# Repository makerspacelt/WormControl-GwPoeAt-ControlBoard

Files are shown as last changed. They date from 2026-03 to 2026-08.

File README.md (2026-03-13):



---
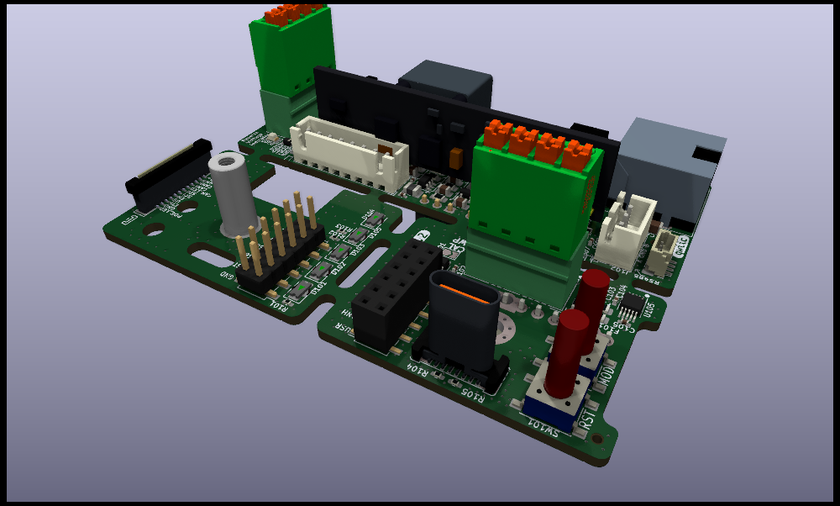
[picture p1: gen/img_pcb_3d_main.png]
PCB 3d main


WormControl Gateway POE.AT

NOTE: This is only a prototype now, so things might not work and everything might change 

Basic target features:

* Compatibility with esphome and Home Assistant

Dev NOTE: before commit, run `./kibot.sh` to regenerate documentation, bom, gerbers and other assets.

* [schematics.pdf](gen/schematics.pdf)
* [pcb.pdf with dimensions](gen/pcb.pdf)
* [ibom.html](gen/single/ibom.html)

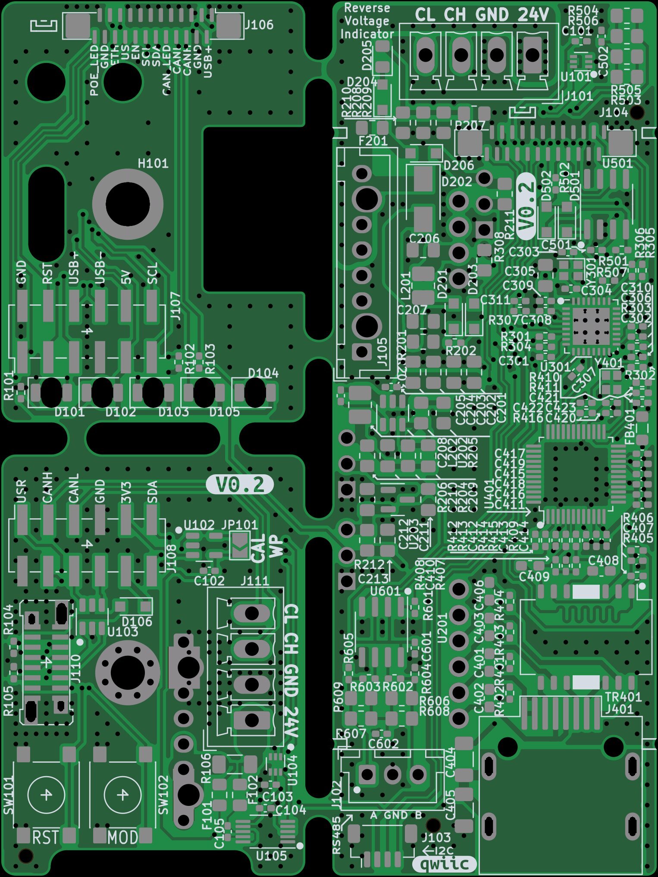
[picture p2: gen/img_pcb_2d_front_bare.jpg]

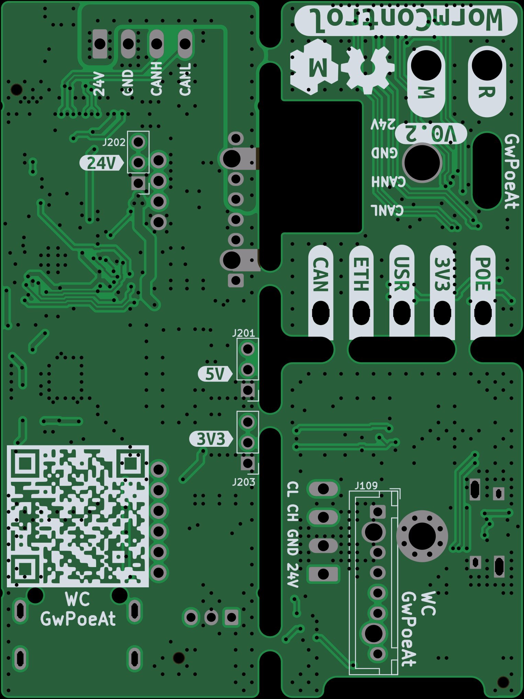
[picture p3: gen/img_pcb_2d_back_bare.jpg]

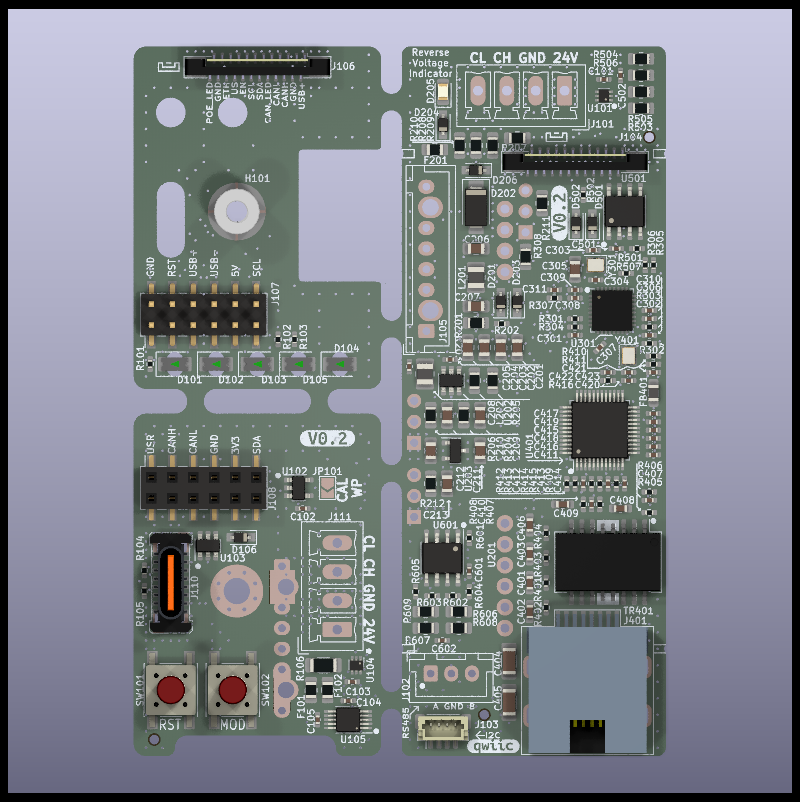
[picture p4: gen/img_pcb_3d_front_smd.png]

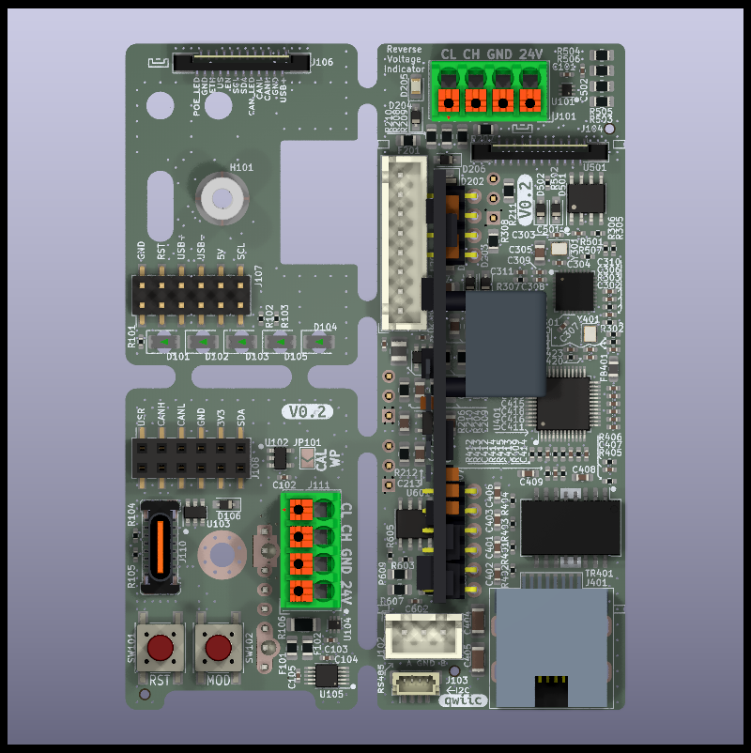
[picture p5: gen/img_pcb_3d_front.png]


---

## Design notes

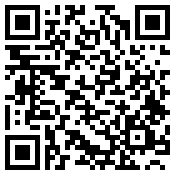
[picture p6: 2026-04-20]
gen/qr_link.png

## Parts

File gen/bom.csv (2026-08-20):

Row | Description | Part | References | Value | Footprint | Quantity Per PCB | Status | Datasheet | lcsc# | jlc-part-type | alt#
1 | Heatsink | Heatsink | BOM101,BOM102 | 1x4 screw plug | ~ | 2 |  | https://www.lcsc.com/datasheet/C7603442.pdf | C7603442 | E+
2 | Unpolarized capacitor | C | C303,C304,C422,C423 | 10p | C_0402_1005Metric_Pad0.74x0.62mm_HandSolder | 4 |  | ~ | C32949 | B+
3 | Unpolarized capacitor | C | C209 | 100p | C_0805_2012Metric_Pad1.18x1.45mm_HandSolder | 1 |  | ~ | C1790 | B+
4 | Unpolarized capacitor | C | C408,C409 | 6n8 | C_0603_1608Metric_Pad1.08x0.95mm_HandSolder | 2 |  | ~ | C1631 | B+
5 | Unpolarized capacitor | C | C101,C102,C103,C104,C105,C301,C302,C306,C307,C308,C309,C310,C311,C407,C410,C412,C413,C414,C416,C417,C418,C419,C420,C501,C502,C601,C602 | 100n | C_0402_1005Metric_Pad0.74x0.62mm_HandSolder | 27 |  | ~ | C1525 | B+
6 | Unpolarized capacitor | C | C415 | 4u7 | C_0402_1005Metric_Pad0.74x0.62mm_HandSolder | 1 |  | ~ | C23733 | B+
7 | Unpolarized capacitor | C | C205,C208 | 100n/50V | C_0402_1005Metric_Pad0.74x0.62mm_HandSolder | 2 |  | ~ | C307331 | B+
8 | Unpolarized capacitor | C | C201,C202,C203,C204,C206,C207,C210 | 10u/50v | C_0805_2012Metric_Pad1.18x1.45mm_HandSolder | 7 |  | ~ | C440198 | B+
9 | Unpolarized capacitor | C | C411,C421 | 10u/6v3 | C_0402_1005Metric_Pad0.74x0.62mm_HandSolder | 2 |  | ~ | C15525 | B+
10 | Unpolarized capacitor | C | C404 | 1n/2kv | C_1206_3216Metric_Pad1.33x1.80mm_HandSolder | 1 |  | ~ | C9196 | B+
11 | Unpolarized capacitor | C | C401,C402,C403,C406 | 22n/100v | C_0603_1608Metric_Pad1.08x0.95mm_HandSolder | 4 |  | ~ | C22374871 | E+
12 | Unpolarized capacitor | C | C211,C305 | 22u/25v | C_0805_2012Metric_Pad1.18x1.45mm_HandSolder | 2 |  | ~ | C45783 | B+
13 | Unpolarized capacitor | C | C212,C213 | 47u/6V3 | C_0805_2012Metric_Pad1.18x1.45mm_HandSolder | 2 |  | ~ | C16780 | B+
14 | Unpolarized capacitor | C | C405 | 4n7/2kv | C_1206_3216Metric_Pad1.33x1.80mm_HandSolder | 1 |  | ~ | C41017 | E+
15 | Zener diode | D_Zener | D203 | 6V8 | D_SOD-323_HandSoldering | 1 |  | https://www.lcsc.com/datasheet/C123062.pdf | C123062 | E+
16 | Schottky diode | D_Schottky | D106,D201,D204,D206,D501,D502 | B5819WS | D_SOD-323_HandSoldering | 6 |  | https://www.lcsc.com/datasheet/C8598.pdf | C8598 | B+
17 | Light emitting diode | LED | D205 | BLUE | LED_0805_2012Metric_Pad1.15x1.40mm_HandSolder | 1 |  | https://www.lcsc.com/datasheet/C2297.pdf | C2297 | B+
18 | Light emitting diode | LED | D101,D102,D103,D104,D105 | RED | LED_1206_3216Metric_ReverseMount | 5 |  | https://www.lcsc.com/datasheet/C5356080.pdf | C5356080 | E+
19 | Schottky diode | D_Schottky | D202 | SS34 | D_SMA | 1 |  | https://www.lcsc.com/datasheet/C8678.pdf | C8678 | B+
20 | Resettable fuse, polymeric positive temperature coefficient | Polyfuse | F101,F102 | 10mA | Fuse_0805_2012Metric_Pad1.15x1.40mm_HandSolder | 2 |  | https://www.lcsc.com/datasheet/C7472543.pdf | C7472543 | E+
21 | Resettable fuse, polymeric positive temperature coefficient | Polyfuse | F201 | 250mA | Fuse_0805_2012Metric_Pad1.15x1.40mm_HandSolder | 1 |  | https://www.lcsc.com/datasheet/C22378353.pdf | C22378353 | E+
22 | Ferrite bead, small symbol | FerriteBead_Small | FB401 | 600R@100MHz | L_0805_2012Metric_Pad1.05x1.20mm_HandSolder | 1 |  | ~ | C1017 | B+
23 | Generic connector, single row, 01x03, script generated (kicad-library-utils/schlib/autogen/connector/) | Conn_01x03 | J201,J202,J203 | 5V | PinHeader_1x03_P2.54mm_Vertical | 3 |  | ~ |  | -
24 | Generic screw terminal, single row, 01x04, script generated (kicad-library-utils/schlib/autogen/connector/) | Screw_Terminal_01x04 | J101,J111 | BUS | PhoenixContact_MCV_1,5_4-G-3.5_1x04_P3.50mm_Vertical | 2 |  | https://www.lcsc.com/datasheet/C880556.pdf | C880556 | E+
25 | Generic connector, single row, 01x08, script generated (kicad-library-utils/schlib/autogen/connector/) | Conn_01x08 | J105,J109 | Bot | JST_XH_B8B-XH-A_1x08_P2.50mm_Vertical | 2 |  | ~ |  | ???
26 | Generic connectable mounting pin connector, single row, 01x24, script generated (kicad-library-utils/schlib/autogen/connector/) | Conn_01x24_MountingPin | J104,J106 | FFC | AFC11-S24ICC-00 | 2 |  | https://www.lcsc.com/datasheet/C11075.pdf | C11075 | E+
27 | Generic connector, single row, 01x12, script generated (kicad-library-utils/schlib/autogen/connector/) | Conn_01x12 | J108 | Mid | PinSocket_2x06_P2.54mm_Vertical_SMD | 1 |  | https://www.lcsc.com/datasheet/C3975151.pdf | C3975151 | E+
28 | RJ connector, 8P8C (8 positions 8 connected), Shielded | RJ45_Shielded | J401 | RJ45_Shielded | RJ45_FG_RJ-064-1 | 1 |  | https://www.lcsc.com/datasheet/C7205199.pdf | C7205199 | E+
29 | Generic connector, single row, 01x12, script generated (kicad-library-utils/schlib/autogen/connector/) | Conn_01x12 | J107 | Top | PinHeader_2x06_P2.54mm_Vertical_SMD | 1 |  | https://www.lcsc.com/datasheet/C5160780.pdf | C5160780 | E+
30 | USB 2.0-only Type-C Receptacle connector | USB_C_Receptacle_USB2.0 | J110 | USB_C_Receptacle_USB2.0 | USB_C_Receptacle_G-Switch_GT-USB-7082G | 1 |  | https://www.lcsc.com/datasheet/C22383836.pdf | C22383836 | E+
31 | Generic connectable mounting pin connector, single row, 01x04, script generated (kicad-library-utils/schlib/autogen/connector/) | Conn_01x04_MountingPin | J103 | qwiic | JST_SH_BM04B-SRSS-TB_1x04-1MP_P1.00mm_Vertical | 1 |  | https://www.lcsc.com/datasheet/C51940129.pdf | C51940129 | E+
32 | Generic connector, single row, 01x03, script generated (kicad-library-utils/schlib/autogen/connector/) | Conn_01x03 | J102 | rs485 | JST_XH_B3B-XH-A_1x03_P2.50mm_Vertical | 1 |  | ~ |  | ???
33 | Inductor | L | L201,L202 | 3.3uH | L_1008_2520Metric_Pad1.43x2.20mm_HandSolder | 2 |  | https://www.lcsc.com/datasheet/C5832373.pdf | C5832373 | E+
34 | Resistor | R | R106 | 10m | R_1206_3216Metric_Pad1.30x1.75mm_HandSolder | 1 |  | ~ | C7467248 | E+
35 | Resistor | R | R206,R211,R212 | 0R1 | R_0805_2012Metric_Pad1.20x1.40mm_HandSolder | 3 |  |  | C127687 | E+
36 | Resistor | R | R602,R603 | 10R | R_0402_1005Metric_Pad0.72x0.64mm_HandSolder | 2 |  | ~ | C25077 | B+
37 | Resistor | R | R305,R306 | 22R | R_0402_1005Metric_Pad0.72x0.64mm_HandSolder | 2 |  | ~ | C25092 | B+
38 | Resistor | R | R412,R413,R414,R415 | 33R | R_0402_1005Metric_Pad0.72x0.64mm_HandSolder | 4 |  | ~ | C25105 | B+
39 | Resistor | R | R405,R406,R407,R408 | 49R9 | R_0402_1005Metric_Pad0.72x0.64mm_HandSolder | 4 |  | ~ | C25120 | B+
40 | Resistor | R | R401,R402,R403,R404 | 75R | R_0402_1005Metric_Pad0.72x0.64mm_HandSolder | 4 |  | ~ | C25133 | ER+
41 | Resistor | R | R503,R504,R505,R506,R606,R607,R608,R609 | 120R | R_0805_2012Metric_Pad1.20x1.40mm_HandSolder | 8 |  | ~ | C17437 | B+
42 | Resistor | R | R501 | 1k5 | R_0402_1005Metric_Pad0.72x0.64mm_HandSolder | 1 |  | ~ | C4310 | B+
43 | Resistor | R | R507 | 3k | R_0402_1005Metric_Pad0.72x0.64mm_HandSolder | 1 |  | ~ | C17661 | B+
44 | Resistor | R | R101,R102,R103,R104,R105,R301,R302,R303,R304,R307,R410,R502,R601 | 4k7 | R_0402_1005Metric_Pad0.72x0.64mm_HandSolder | 13 |  | ~ | C25900 | B+
45 | Resistor | R | R207,R208,R209,R210 | 4k7 | R_0805_2012Metric_Pad1.20x1.40mm_HandSolder | 4 |  | ~ | C17673 | B+
46 | Resistor | R | R201,R203,R205 | 10k | R_0805_2012Metric_Pad1.20x1.40mm_HandSolder | 3 |  | ~ | C17414 | B+
47 | Resistor | R | R604,R605 | 10k | R_0402_1005Metric_Pad0.72x0.64mm_HandSolder | 2 |  | ~ | C25744 | B+
48 | Resistor | R | R409,R411 | 12k4 | R_0402_1005Metric_Pad0.72x0.64mm_HandSolder | 2 |  | ~ | C11692 | E+
49 | Resistor | R | R202 | 47k | R_0402_1005Metric_Pad0.72x0.64mm_HandSolder | 1 |  | ~ | C25792 | B+
50 | Resistor | R | R204,R308 | 150k | R_0805_2012Metric_Pad1.20x1.40mm_HandSolder | 2 |  | ~ | C17470 | B+
51 | Resistor | R | R416 | 1M | R_0402_1005Metric_Pad0.72x0.64mm_HandSolder | 1 |  | ~ | C26083 | B+
52 | Push button switch, generic, two pins | SW_Push | SW101,SW102 | 15mm | SW_SPST_15 | 2 |  | https://www.lcsc.com/datasheet/C2885154.pdf | C2885154 | E+
53 | Ethernet LAN 10/100 Base-Tx Transformer CT, SMD | Wuerth_749013011A | TR401 | CND-tek-H1102N | Transformer_Ethernet_SO-16_7.11x12.7mm | 1 |  | https://www.lcsc.com/datasheet/C42418465.pdf | C42418465 | E+
54 | I2C Serial EEPROM, 2Kb (256x8) with Unique Serial Number, SOT-23-5 | AT24CS02-STUM | U102 | 24C02S | SOT-23-5 | 1 |  | http://ww1.microchip.com/downloads/en/DeviceDoc/Atmel-8815-SEEPROM-AT24CS01-02-Datasheet.pdf | C18723540 | E+
55 |  | DP9700AT-24 | U201 | DP9700AT-24 | DP9700AT | 1 |  | https://www.lcsc.com/datasheet/C5380094.pdf | C5380094 | E+
56 | High-Side or Low-Side Measurement, Bi-Directional Current and Power Monitor (0-36V) with I2C Compatible Interface, VSSOP-10 | INA226 | U105 | INA226 | VSSOP-10_3x3mm_P0.5mm | 1 |  | http://www.ti.com/lit/ds/symlink/ina226.pdf | C49851 | E+ | C2653870
57 | 300mA Low Dropout Voltage Regulator, Fixed Output 3.3V, SOT-23 | APE8865N-33-HF-3 | U203 | JTD6206-3.3V | SOT-23 | 1 |  | https://www.lcsc.com/datasheet/C42443428.pdf | C5446 | B+ | C42443428
58 | Half duplex RS-485/RS-422, 0.25 Mbps, ±15kV electro-static discharge (ESD) protection, with slew-rate, with low-power shutdown, with receiver/driver enable, 128 receiver drive kapacitity, DIP-8 and SOIC-8 | MAX487E | U601 | MAX13487E | SOIC-8_3.9x4.9mm_P1.27mm | 1 |  | https://www.lcsc.com/datasheet/C18347.pdf | C18347 | E+
59 | 1.2 A Simple Buck Regulator, 3-26V input, 1.5Mhz | AOZ1280CI | U202 | ME3121AM6G | SOT-23-6 | 1 |  | https://m.huazhoucn.com/upFiles/common/2022/12/ME3121_Series_E1.0.pdf | C2932938 | E+
60 | Digital Temperature Sensor, +/- 3 °C, low-Power, SMBus, 12 bit, Two-Wire Serial Interface, SOT-563 | TMP102xxDRL | U101,U104 | TMP102 | SOT-563 | 2 |  | https://www.ti.com/lit/ds/symlink/tmp102.pdf | C99269 | E+
61 | Very low capacitance ESD protection diode, 2 data-line, SOT-23-6 | USBLC6-2SC6 | U103 | USBLC6-2SC6 | SOT-23-6 | 1 |  | https://www.lcsc.com/datasheet/C2687116.pdf | C2687116 | E+
62 | 10/100Mb SPI Ethernet controller with TCP/IP stack, LQFP-48 | W5500 | U401 | W5500 | LQFP-48_7x7mm_P0.5mm | 1 |  | https://www.lcsc.com/datasheet/C32843.pdf | C32843 | E+
63 | High-Speed CAN Transceiver, standby mode, split pin, SOIC-8 | TJA1042T | U501 | XL1050 | SOIC-8_3.9x4.9mm_P1.27mm | 1 |  | https://www.lcsc.com/datasheet/C609746.pdf | C609746 | E+
64 | esp32-C3FH4X 4MB flash QFN32-1EP 5x5mm EP3.7x3.7mm | esp32-C3FH4X | U301 | esp32-C3FH4X | QFN-32-1EP_5x5mm_P0.5mm_EP3.65x3.65mm | 1 |  | https://www.espressif.com/sites/default/files/documentation/esp32-c3_datasheet_en.pdf | C2858491 | E+
65 | Four pin crystal, GND on pins 2 and 4 | Crystal_GND24 | Y401 | 25MHz | Crystal_SMD_2016-4Pin_2.0x1.6mm | 1 |  | https://www.lcsc.com/datasheet/C7301943.pdf | C7301943 | E+
66 | Four pin crystal, GND on pins 2 and 4 | Crystal_GND24 | Y301 | 40MHz | Crystal_SMD_2016-4Pin_2.0x1.6mm | 1 |  | https://www.lcsc.com/datasheet/C20885029.pdf | C20885029 | E+

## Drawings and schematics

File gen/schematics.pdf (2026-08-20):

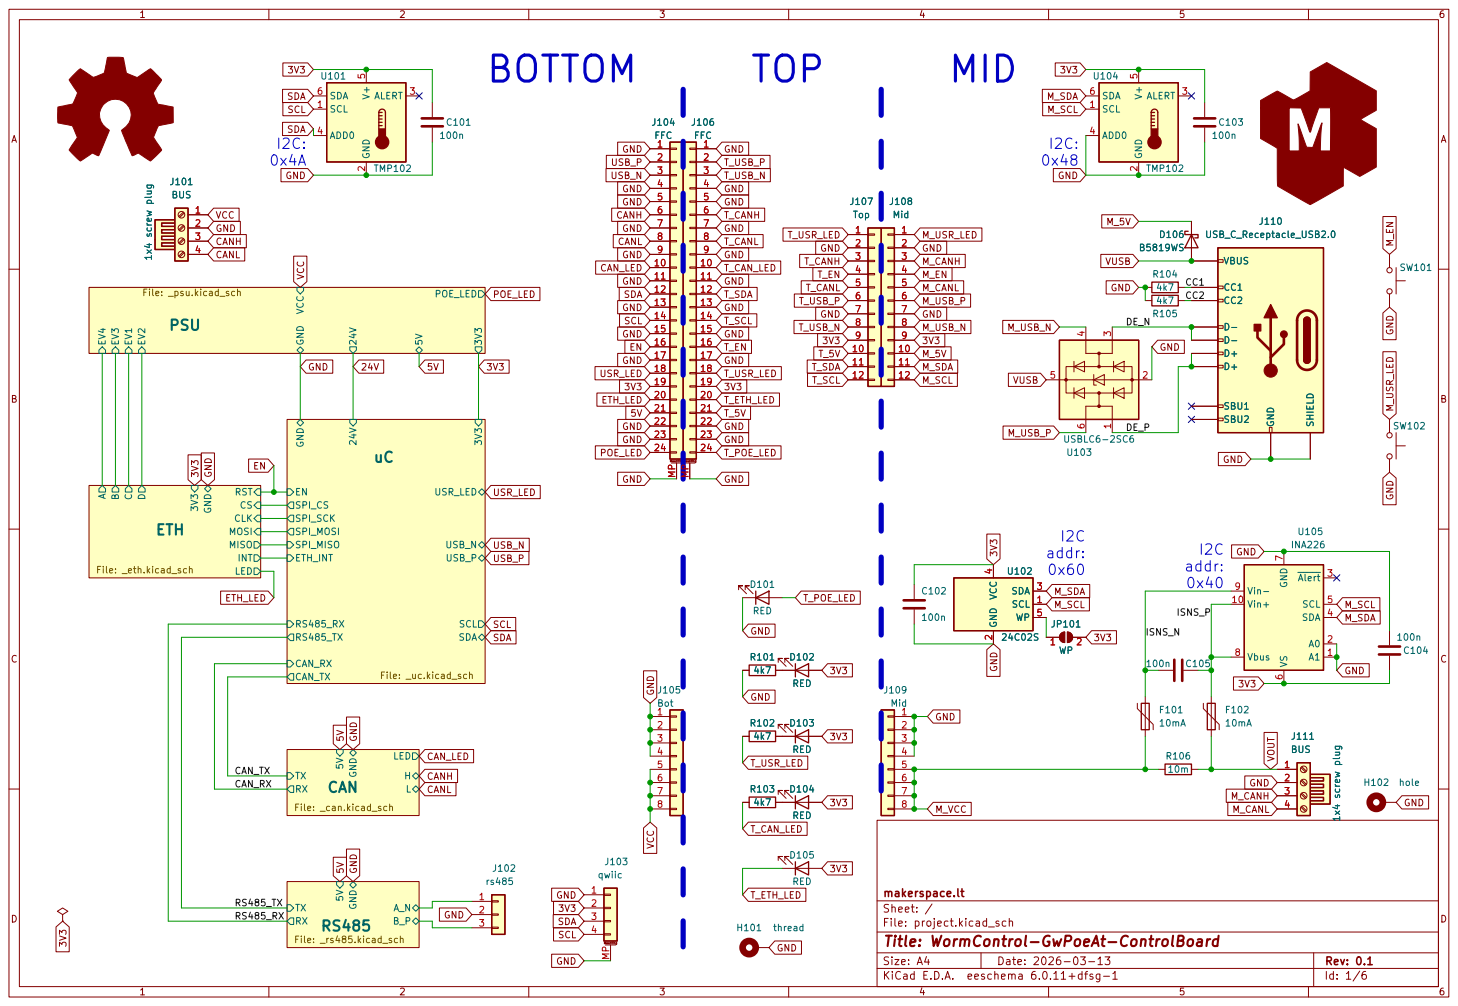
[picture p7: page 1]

Id: 1/6 Title: WormControl-GwPoeAt-ControlBoard

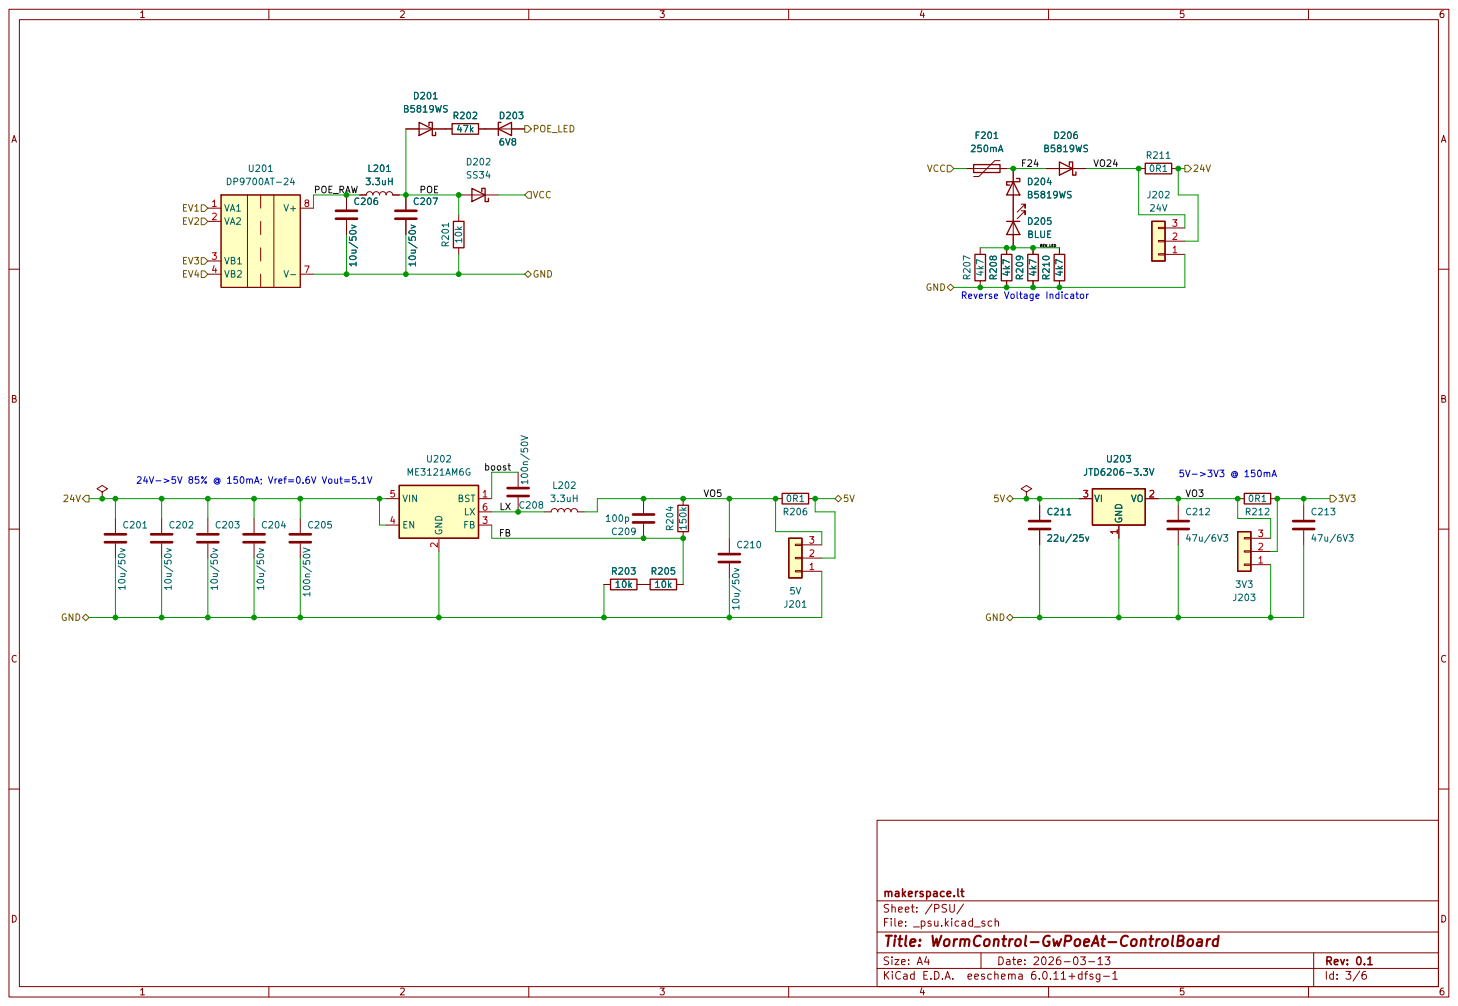
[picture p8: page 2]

Id: 3/6 Title: WormControl-GwPoeAt-ControlBoard

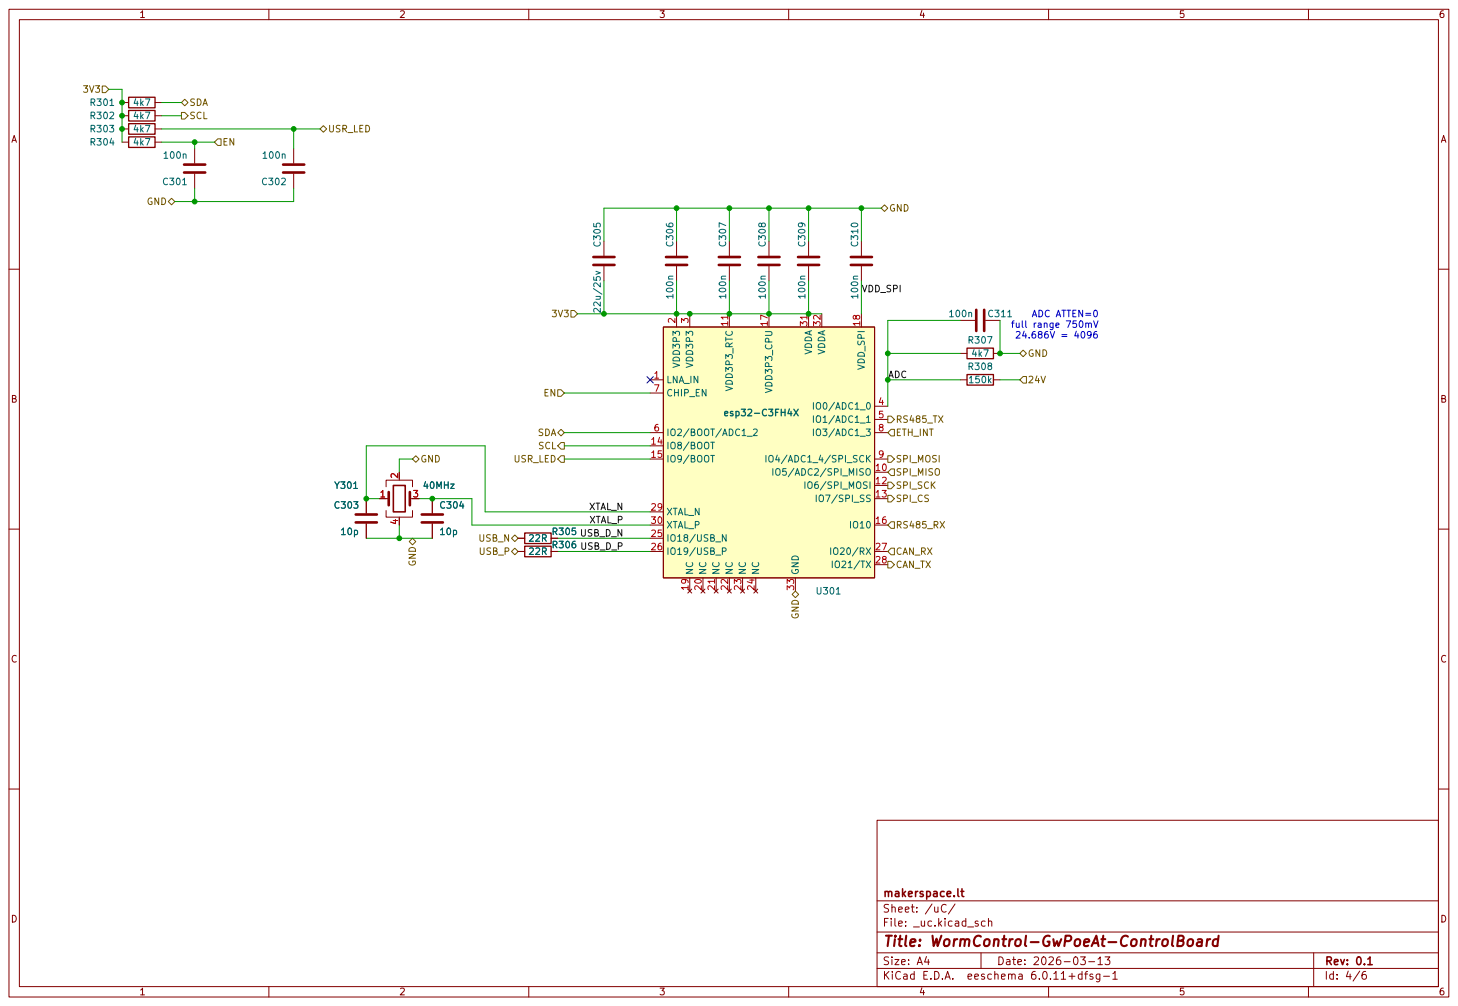
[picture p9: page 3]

File: _uc.kicad_sch Sheet: /uC/ makerspace.lt C308 100n

Id: 4/6 Title: WormControl-GwPoeAt-ControlBoard

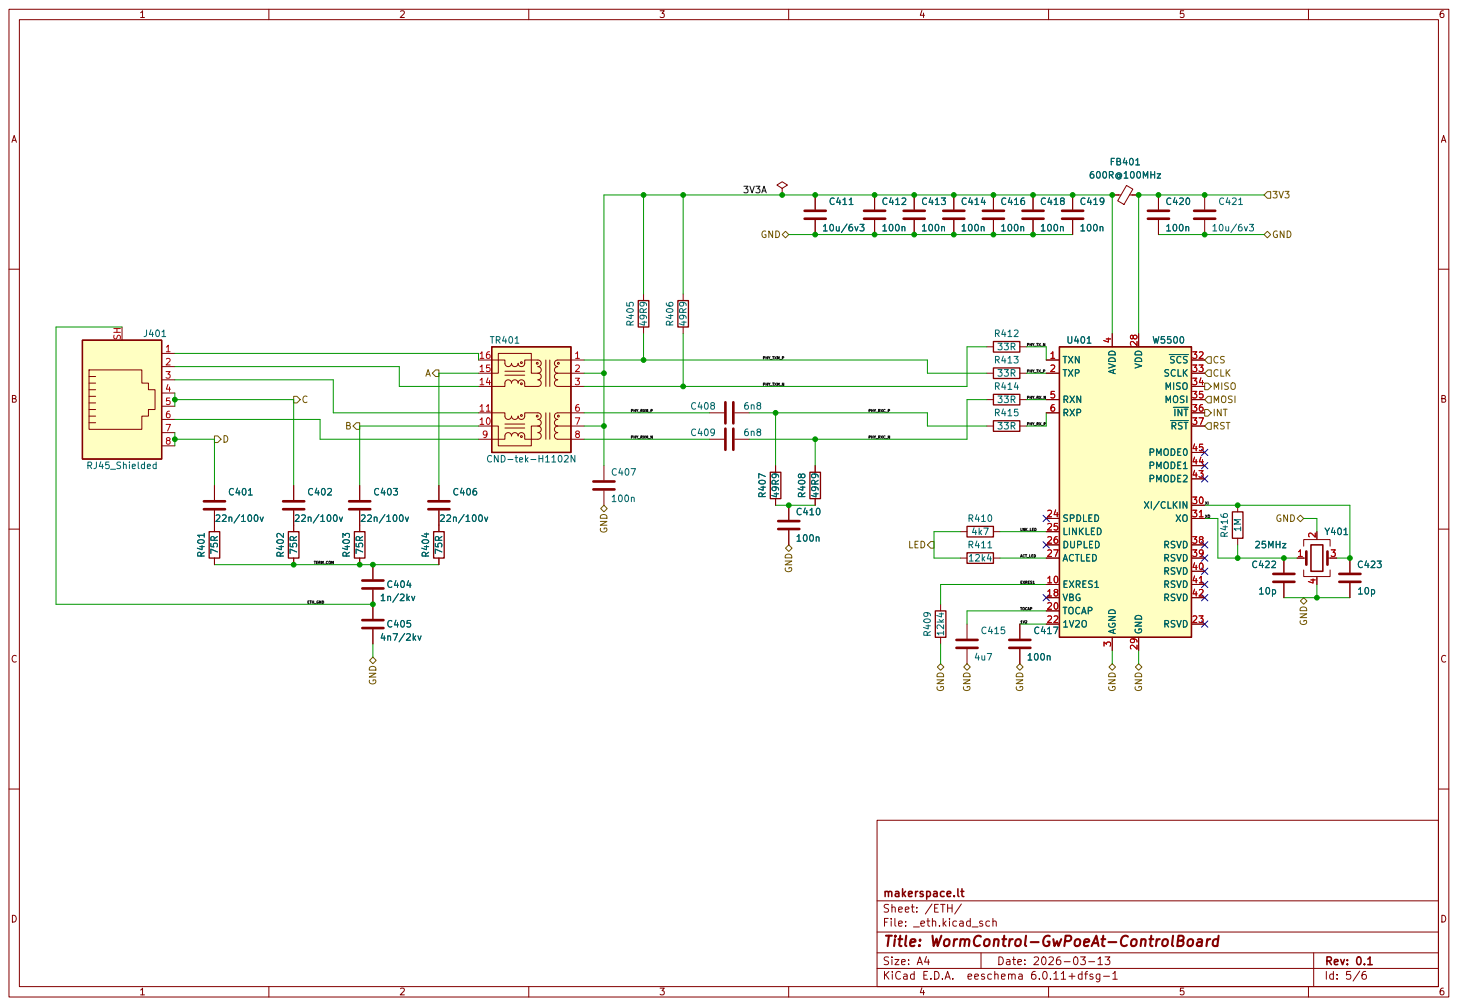
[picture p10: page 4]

4 RSVD 40 RSVD 41 RSVD 42 PMODE2 43 PMODE1 44 PMODE0 45 RXN

3 XI/CLKIN 30 XO 31 ~{SCS} 32 SCLK 33 MISO 34 MOSI 35 ~{INT} 36 ~{RST} 37 RSVD 38 RSVD 39 AVDD

File: _eth.kicad_sch Sheet: /ETH/ makerspace.lt C401

Id: 5/6 Title: WormControl-GwPoeAt-ControlBoard

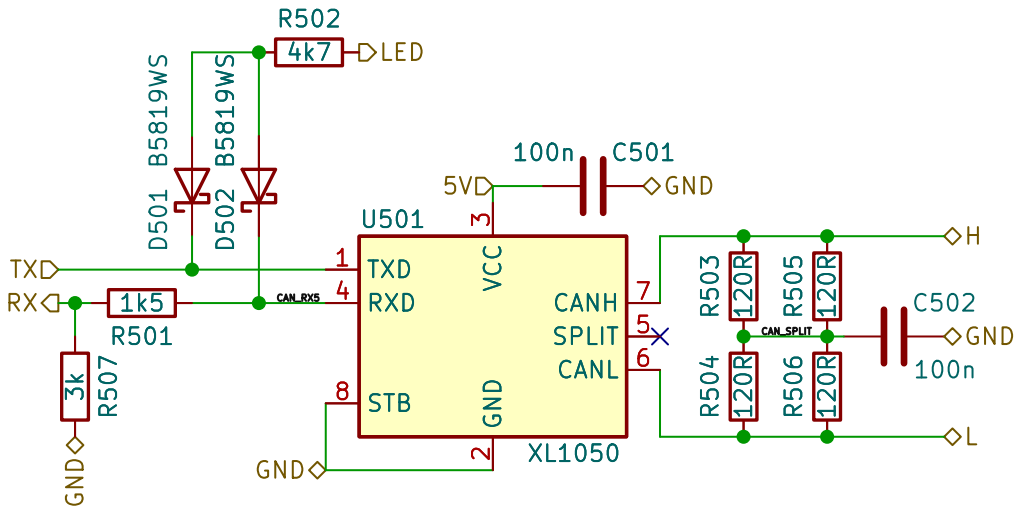
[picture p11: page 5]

Id: 5/6 Title: WormControl-GwPoeAt-ControlBoard

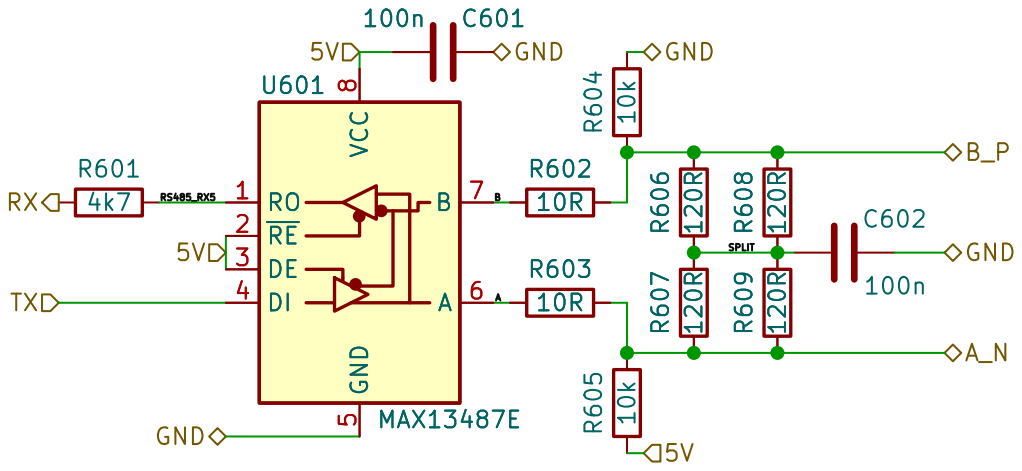
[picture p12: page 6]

File: _rs485.kicad_sch Sheet: /RS485/ makerspace.lt R601

Id: 6/6 Title: WormControl-GwPoeAt-ControlBoard

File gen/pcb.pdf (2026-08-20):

64.5 mm

## CL CH GND 24V

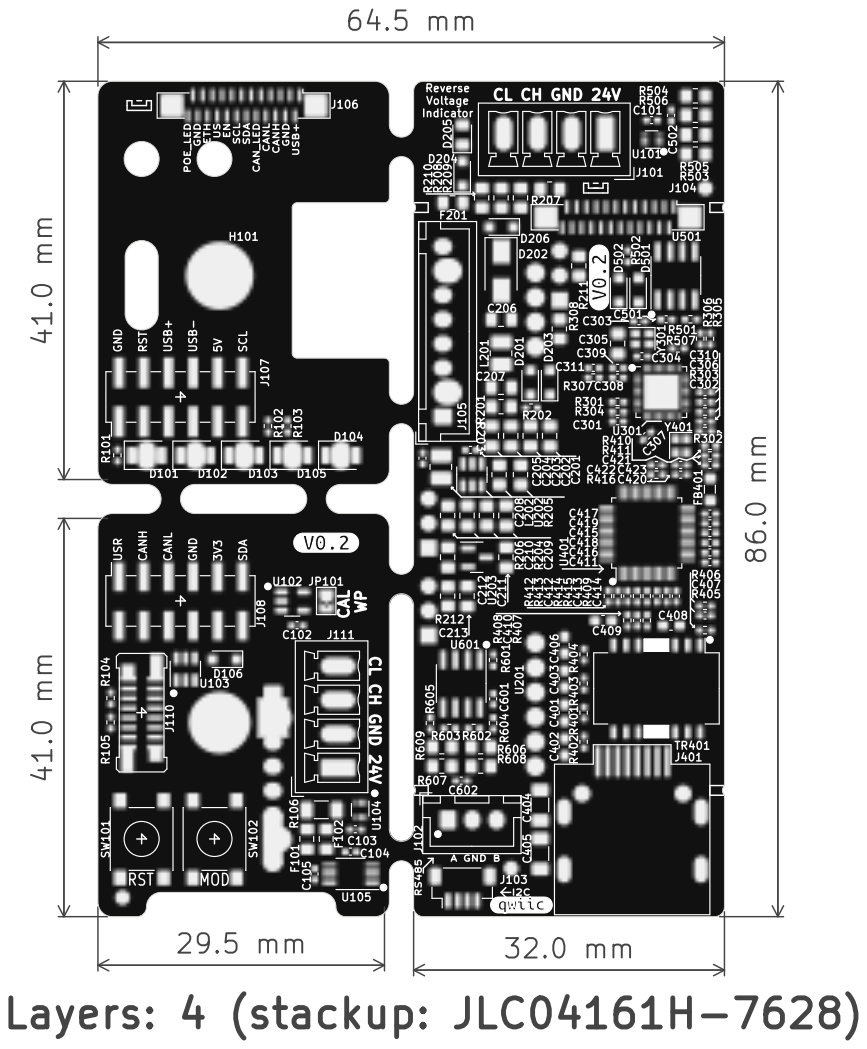
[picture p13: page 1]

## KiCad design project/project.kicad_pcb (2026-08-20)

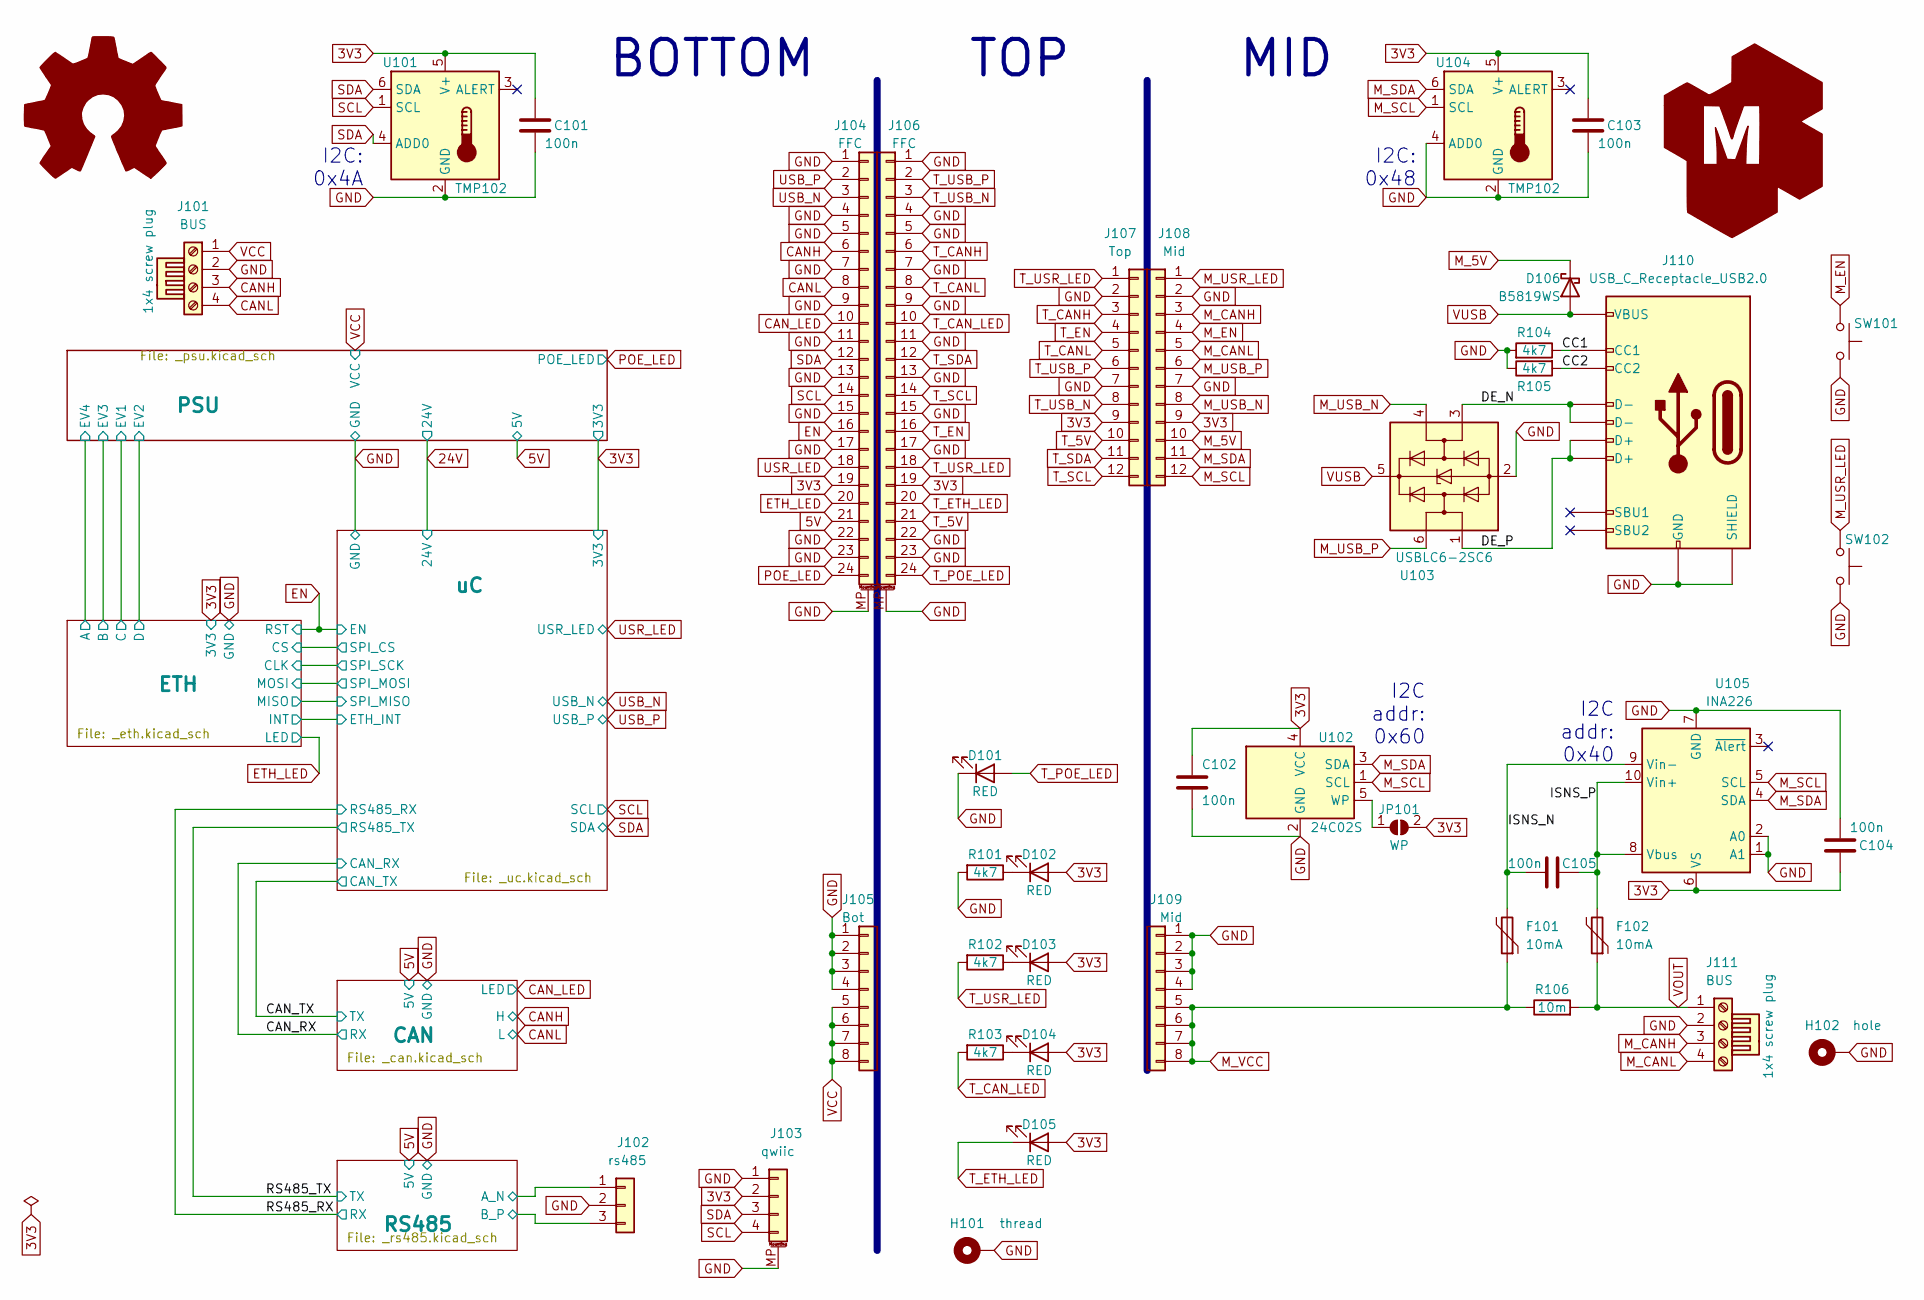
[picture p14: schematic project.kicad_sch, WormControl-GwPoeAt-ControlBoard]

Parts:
BOM101, BOM102: 1x4 screw plug; jlc-part-type E+
C101, C102, C103, C104, C105: 100n; C_0402_1005Metric_Pad0.74x0.62mm_HandSolder; jlc-part-type B+
D101, D102, D103, D104, D105: RED; LED_1206_3216Metric_ReverseMount; jlc-part-type E+
D106: B5819WS; D_SOD-323_HandSoldering; jlc-part-type B+
F101, F102: 10mA; Fuse_0805_2012Metric_Pad1.15x1.40mm_HandSolder; lcsc# C7472543
G101: Logo_Open_Hardware_Large; OSHW-Symbol_6.7x6mm_SilkScreen
G102: LOGO_KMS; logo_kms_small_silkscreen
H101: thread; post_m3x12.5mm; lcsc# C30182781
H102: hole; MountingHole_3.2mm_M3_Pad_Via
J101, J111: BUS; PhoenixContact_MCV_1,5_4-G-3.5_1x04_P3.50mm_Vertical; jlc-part-type E+
J102: rs485; JST_XH_B3B-XH-A_1x03_P2.50mm_Vertical; jlc-part-type ???
J103: qwiic; JST_SH_BM04B-SRSS-TB_1x04-1MP_P1.00mm_Vertical; jlc-part-type E+
J104, J106: FFC; AFC11-S24ICC-00; jlc-part-type E+
J105: Bot; JST_XH_B8B-XH-A_1x08_P2.50mm_Vertical; jlc-part-type ???
J107: Top; PinHeader_2x06_P2.54mm_Vertical_SMD; lcsc# C5160780
J108: Mid; PinSocket_2x06_P2.54mm_Vertical_SMD; lcsc# C3975151
J109: Mid; JST_XH_B8B-XH-A_1x08_P2.50mm_Vertical; jlc-part-type ???
J110: USB_C_Receptacle_USB2.0; USB_C_Receptacle_G-Switch_GT-USB-7082G; jlc-part-type E+
JP101: WP; SolderJumper-2_P1.3mm_Open_TrianglePad1.0x1.5mm
R101, R102, R103, R104, R105: 4k7; R_0402_1005Metric_Pad0.72x0.64mm_HandSolder; jlc-part-type B+
R106: 10m; R_1206_3216Metric_Pad1.30x1.75mm_HandSolder; jlc-part-type E+
SW101, SW102: 15mm; SW_SPST_15; jlc-part-type E+
U101, U104: TMP102; SOT-563; jlc-part-type E+
U102: 24C02S; SOT-23-5; jlc-part-type E+
U103: USBLC6-2SC6; SOT-23-6; jlc-part-type E+
U105: INA226; VSSOP-10_3x3mm_P0.5mm; jlc-part-type E+

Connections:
3V3: C101.1, C102.2, C103.1, C104.1, D102.2 (A), D103.2 (A), D104.2 (A), D105.2 (A), J103.2, J104.19, J106.19, J107.9, J108.9, JP101.2 (B), U101.5 (V+), U102.4 (VCC), U104.5 (V+), U105.6 (VS); also elsewhere on the board
5V: J104.21; also elsewhere on the board
/CC1: J110.A5 (CC1), R104.1
/CC2: J110.B5 (CC2), R105.2
/DE_N: J110.A7 (D-), J110.B7 (D-), U103.3 (I/O2)
/DE_P: J110.A6 (D+), J110.B6 (D+), U103.1 (I/O1)
/ISNS_N: C105.2, F101.2, U105.9 (Vin-)
/ISNS_P: C105.1, F102.2, U105.8 (Vbus), U105.10 (Vin+)
/RS485/A_N: J102.1; also elsewhere on the board
/RS485/B_P: J102.3; also elsewhere on the board
CANH: J101.3, J104.6; also elsewhere on the board
CANL: J101.4, J104.8; also elsewhere on the board
CAN_LED: J104.10; also elsewhere on the board
EN: J104.16; also elsewhere on the board
ETH_LED: J104.20; also elsewhere on the board
GND: C101.2, C102.1, C103.2, C104.2, D101.1 (K), H101.1, H102.1, J101.2, J102.2, J103.1, J103.MP (MountPin), J104.1, J104.4, J104.5, J104.7, J104.9, J104.11, J104.13, J104.15, J104.17, J104.22, J104.23, J104.MP (MountPin), J105.1, J105.2, J105.3, J105.4, J106.1, J106.4, J106.5, J106.7, J106.9, J106.11, J106.13, J106.15, J106.17, J106.22, J106.23, J106.MP (MountPin), J107.2, J107.7, J108.2, J108.7, J109.1, J109.2, J109.3, J109.4, J110.A1 (GND), J110.A12 (GND), J110.B1 (GND), J110.B12 (GND), J110.S1 (SHIELD), J111.2, R101.2, R104.2, R105.1, SW101.2, SW102.2, U101.2 (GND), U102.2 (GND), U103.2 (GND), U104.2 (GND), U104.4 (ADD0), U105.1 (A1), U105.2 (A0), U105.7 (GND); also elsewhere on the board
M_5V: D106.1 (K), J108.10
M_CANH: J108.3, J111.3
M_CANL: J108.5, J111.4
M_EN: J108.4, SW101.1
M_SCL: J108.12, U102.1 (SCL), U104.1 (SCL), U105.5 (SCL)
M_SDA: J108.11, U102.3 (SDA), U104.6 (SDA), U105.4 (SDA)
M_USB_N: J108.8, U103.4 (I/O2)
M_USB_P: J108.6, U103.6 (I/O1)
M_USR_LED: J108.1, SW102.1
M_VCC: F101.1, J109.5, J109.6, J109.7, J109.8, R106.1
unnamed: D102.1 (K), R101.1
unnamed: D103.1 (K), R102.1
unnamed: D104.1 (K), R103.1
unnamed: JP101.1 (A), U102.5 (WP)
POE_LED: J104.24; also elsewhere on the board
SCL: J103.4, J104.14, U101.1 (SCL); also elsewhere on the board
SDA: J103.3, J104.12, U101.4 (ADD0), U101.6 (SDA); also elsewhere on the board
T_5V: J106.21, J107.10
T_CANH: J106.6, J107.3
T_CANL: J106.8, J107.5
T_CAN_LED: J106.10, R103.2
T_EN: J106.16, J107.4
T_ETH_LED: D105.1 (K), J106.20
T_POE_LED: D101.2 (A), J106.24
T_SCL: J106.14, J107.12
T_SDA: J106.12, J107.11
T_USB_N: J106.3, J107.8
T_USB_P: J106.2, J107.6
T_USR_LED: J106.18, J107.1, R102.2
USB_N: J104.3; also elsewhere on the board
USB_P: J104.2; also elsewhere on the board
USR_LED: J104.18; also elsewhere on the board
VCC: J101.1, J105.5, J105.6, J105.7, J105.8; also elsewhere on the board
VOUT: F102.1, J111.1, R106.2
VUSB: D106.2 (A), J110.A4 (VBUS), J110.A9 (VBUS), J110.B4 (VBUS), J110.B9 (VBUS), U103.5 (VBUS)

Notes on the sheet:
I2C addr: 0x40
I2C addr: 0x60
I2C: 0x48
TOP
MID
I2C: 0x4A
BOTTOM

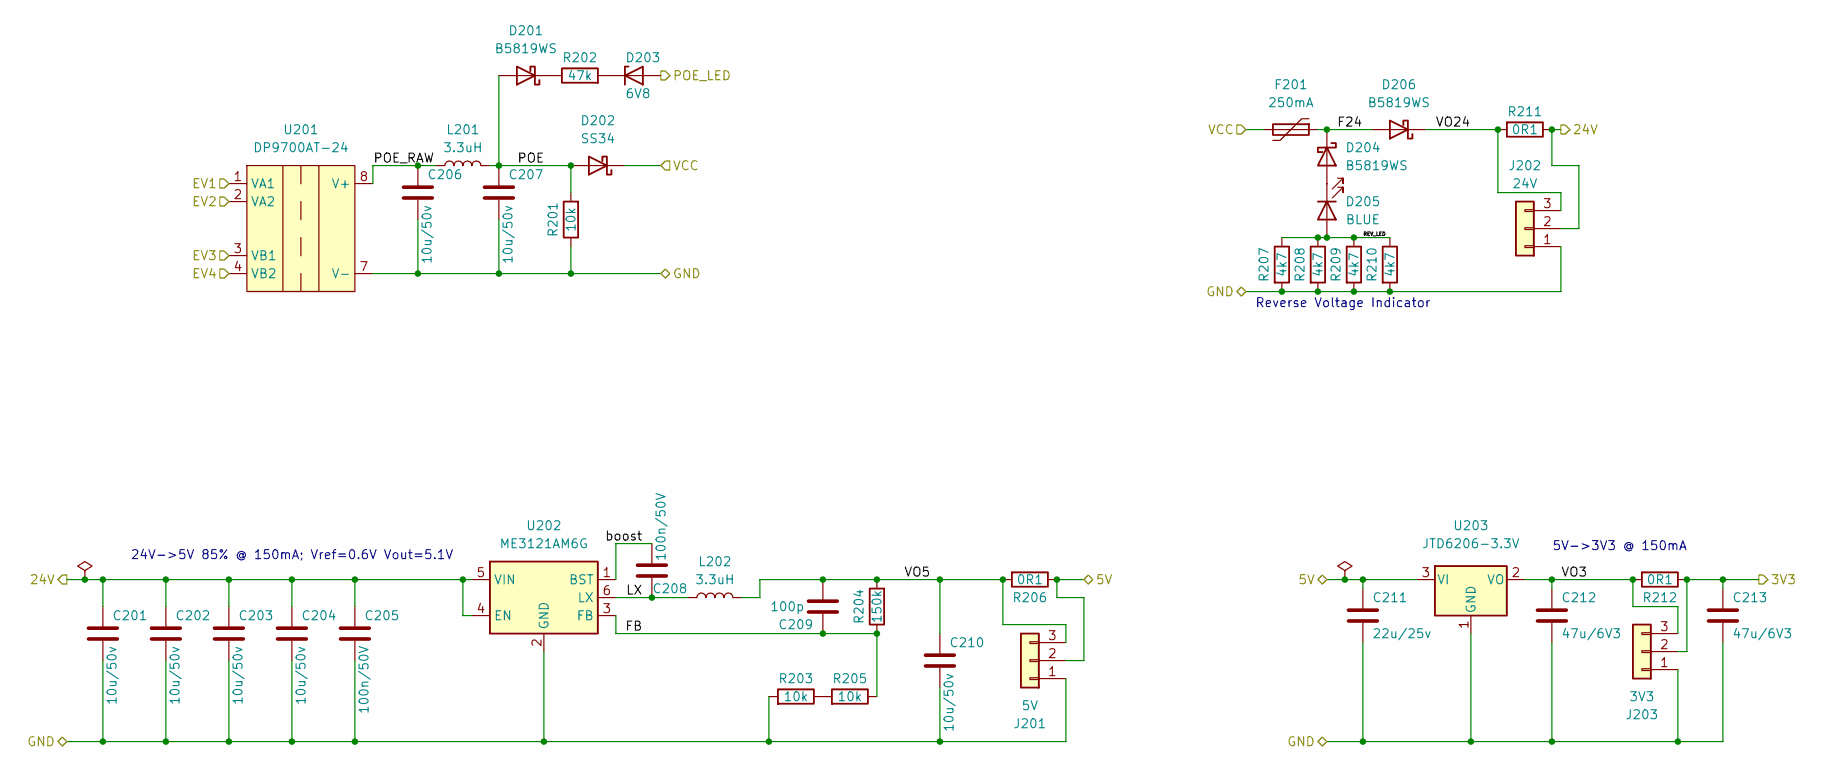
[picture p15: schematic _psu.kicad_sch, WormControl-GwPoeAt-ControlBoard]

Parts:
C201, C202, C203, C204, C206, C207, C210: 10u/50v; C_0805_2012Metric_Pad1.18x1.45mm_HandSolder; jlc-part-type B+
C205, C208: 100n/50V; C_0402_1005Metric_Pad0.74x0.62mm_HandSolder; jlc-part-type B+
C209: 100p; C_0805_2012Metric_Pad1.18x1.45mm_HandSolder; jlc-part-type B+
C211: 22u/25v; C_0805_2012Metric_Pad1.18x1.45mm_HandSolder; jlc-part-type B+
C212, C213: 47u/6V3; C_0805_2012Metric_Pad1.18x1.45mm_HandSolder; jlc-part-type B+
D201, D204, D206: B5819WS; D_SOD-323_HandSoldering; jlc-part-type B+
D202: SS34; D_SMA; jlc-part-type B+
D203: 6V8; D_SOD-323_HandSoldering; jlc-part-type E+
D205: BLUE; LED_0805_2012Metric_Pad1.15x1.40mm_HandSolder; jlc-part-type B+
F201: 250mA; Fuse_0805_2012Metric_Pad1.15x1.40mm_HandSolder; lcsc# C22378353
J201: 5V; PinHeader_1x03_P2.54mm_Vertical
J202: 24V; PinHeader_1x03_P2.54mm_Vertical
J203: 3V3; PinHeader_1x03_P2.54mm_Vertical
L201, L202: 3.3uH; L_1008_2520Metric_Pad1.43x2.20mm_HandSolder; jlc-part-type E+
R201, R203, R205: 10k; R_0805_2012Metric_Pad1.20x1.40mm_HandSolder; jlc-part-type B+
R202: 47k; R_0402_1005Metric_Pad0.72x0.64mm_HandSolder; jlc-part-type B+
R204: 150k; R_0805_2012Metric_Pad1.20x1.40mm_HandSolder; jlc-part-type B+
R206, R211, R212: 0R1; R_0805_2012Metric_Pad1.20x1.40mm_HandSolder; jlc-part-type E+
R207, R208, R209, R210: 4k7; R_0805_2012Metric_Pad1.20x1.40mm_HandSolder; jlc-part-type B+
U201: DP9700AT-24; DP9700AT; jlc-part-type E+
U202: ME3121AM6G; SOT-23-6; jlc-part-type E+
U203: JTD6206-3.3V; SOT-23; jlc-part-type B+

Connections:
3V3: C213.1, J203.2, R212.1; also elsewhere on the board
5V: C211.1, J201.2, R206.1, U203.3 (VI); also elsewhere on the board
24V: C201.1, C202.1, C203.1, C204.1, C205.1, J202.2, R211.1, U202.4 (EN), U202.5 (VIN); also elsewhere on the board
/ETH/A: U201.4 (VB2); also elsewhere on the board
/ETH/B: U201.3 (VB1); also elsewhere on the board
/ETH/C: U201.1 (VA1); also elsewhere on the board
/ETH/D: U201.2 (VA2); also elsewhere on the board
/PSU/F24: D204.1 (K), D206.2 (A), F201.1
/PSU/FB: C209.1, R204.1, R205.1, U202.3 (FB)
/PSU/LX: C208.2, L202.1, U202.6 (LX)
/PSU/POE: C207.1, D201.2 (A), D202.2 (A), L201.2, R201.2
/PSU/POE_RAW: C206.1, L201.1, U201.8 (V+)
/PSU/REV_LED: D205.2 (A), R207.1, R208.1, R209.1, R210.1
/PSU/VO3: C212.1, J203.3, R212.2, U203.2 (VO)
/PSU/VO5: C209.2, C210.1, J201.3, L202.2, R204.2, R206.2
/PSU/VO24: D206.1 (K), J202.3, R211.2
/PSU/boost: C208.1, U202.1 (BST)
GND: C201.2, C202.2, C203.2, C204.2, C205.2, C206.2, C207.2, C210.2, C211.2, C212.2, C213.2, J201.1, J202.1, J203.1, R201.1, R203.2, R207.2, R208.2, R209.2, R210.2, U201.7 (V-), U202.2 (GND), U203.1 (GND); also elsewhere on the board
unnamed: D201.1 (K), R202.1
unnamed: D203.1 (K), R202.2
unnamed: D204.2 (A), D205.1 (K)
unnamed: R203.1, R205.2
POE_LED: D203.2 (A); also elsewhere on the board
VCC: D202.1 (K), F201.2; also elsewhere on the board

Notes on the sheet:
24V->5V 85% @ 150mA; Vref=0.6V Vout=5.1V
5V->3V3 @ 150mA
Reverse Voltage Indicator

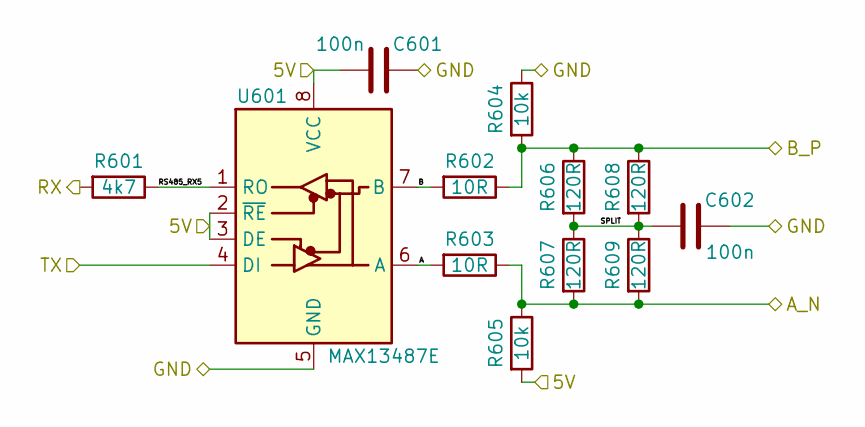
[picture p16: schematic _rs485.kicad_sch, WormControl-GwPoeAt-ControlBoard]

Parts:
C601, C602: 100n; C_0402_1005Metric_Pad0.74x0.62mm_HandSolder; jlc-part-type B+
R601: 4k7; R_0402_1005Metric_Pad0.72x0.64mm_HandSolder; jlc-part-type B+
R602, R603: 10R; R_0402_1005Metric_Pad0.72x0.64mm_HandSolder; jlc-part-type B+
R604, R605: 10k; R_0402_1005Metric_Pad0.72x0.64mm_HandSolder; jlc-part-type B+
R606, R607, R608, R609: 120R; R_0805_2012Metric_Pad1.20x1.40mm_HandSolder; jlc-part-type B+
U601: MAX13487E; SOIC-8_3.9x4.9mm_P1.27mm; jlc-part-type E+

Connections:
5V: C601.1, R605.2, U601.2 (~RE), U601.3 (DE), U601.8 (VCC); also elsewhere on the board
/RS485/A: R603.2, U601.6 (A)
/RS485/A_N: R603.1, R605.1, R607.2, R609.2; also elsewhere on the board
/RS485/B: R602.2, U601.7 (B)
/RS485/B_P: R602.1, R604.2, R606.1, R608.1; also elsewhere on the board
/RS485/RS485_RX5: R601.1, U601.1 (RO)
/RS485/SPLIT: C602.1, R606.2, R607.1, R608.2, R609.1
/RS485_RX: R601.2; also elsewhere on the board
/RS485_TX: U601.4 (DI); also elsewhere on the board
GND: C601.2, C602.2, R604.1, U601.5 (GND); also elsewhere on the board

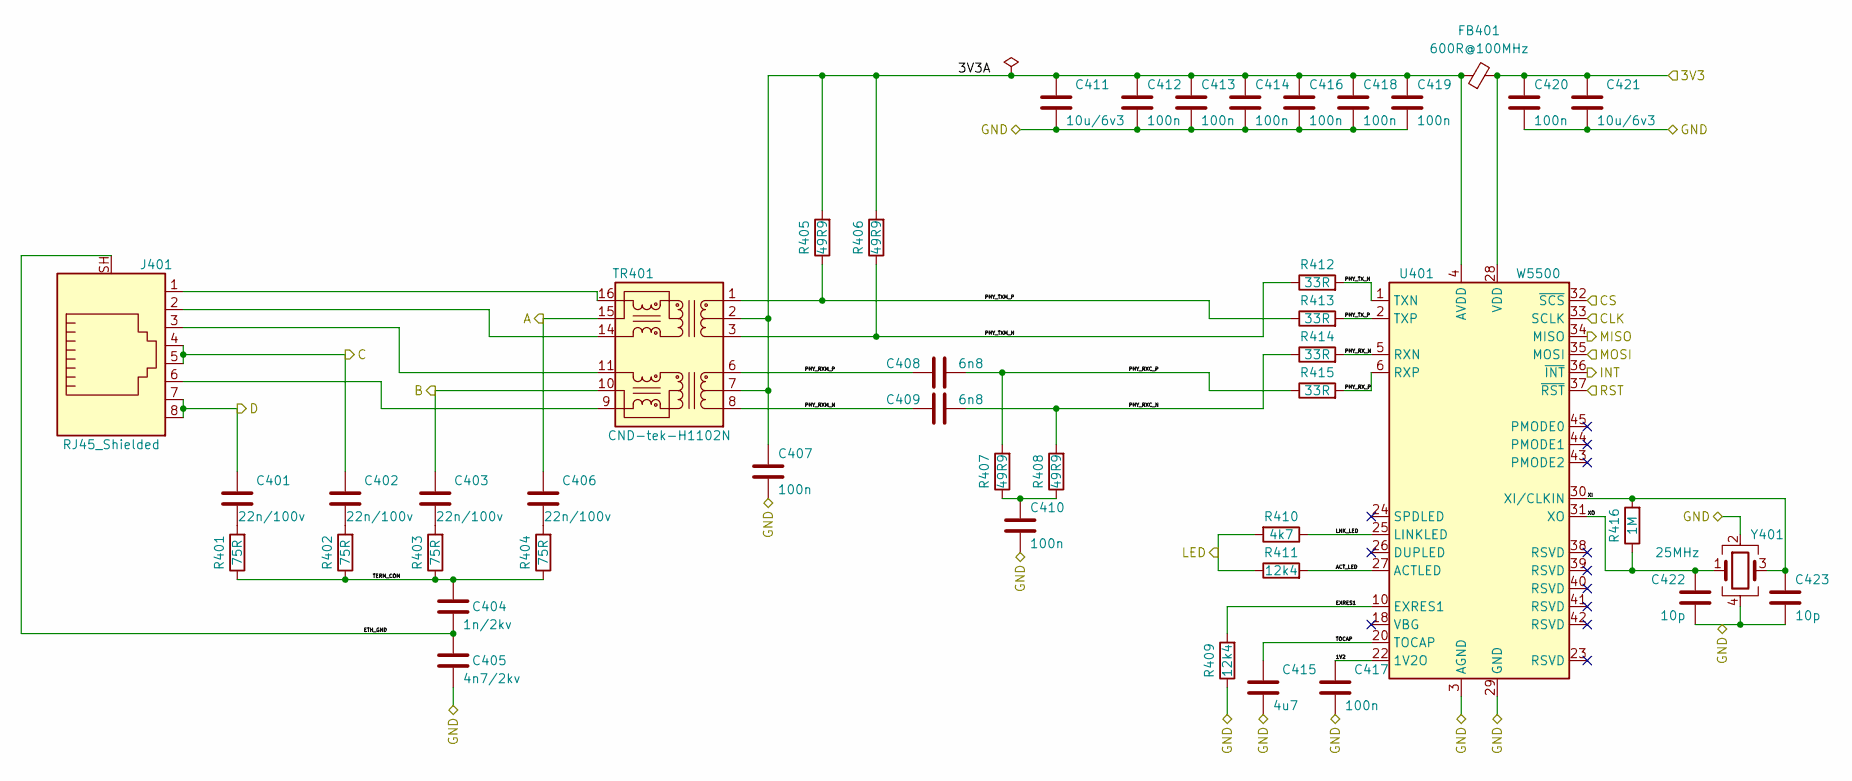
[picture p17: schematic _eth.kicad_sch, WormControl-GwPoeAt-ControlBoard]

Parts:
C401, C402, C403, C406: 22n/100v; C_0603_1608Metric_Pad1.08x0.95mm_HandSolder; jlc-part-type E+
C404: 1n/2kv; C_1206_3216Metric_Pad1.33x1.80mm_HandSolder; jlc-part-type B+
C405: 4n7/2kv; C_1206_3216Metric_Pad1.33x1.80mm_HandSolder; jlc-part-type E+
C407, C410, C412, C413, C414, C416, C417, C418, C419, C420: 100n; C_0402_1005Metric_Pad0.74x0.62mm_HandSolder; jlc-part-type B+
C408, C409: 6n8; C_0603_1608Metric_Pad1.08x0.95mm_HandSolder; jlc-part-type B+
C411, C421: 10u/6v3; C_0402_1005Metric_Pad0.74x0.62mm_HandSolder; jlc-part-type B+
C415: 4u7; C_0402_1005Metric_Pad0.74x0.62mm_HandSolder; jlc-part-type B+
C422, C423: 10p; C_0402_1005Metric_Pad0.74x0.62mm_HandSolder; jlc-part-type B+
FB401: 600R@100MHz; L_0805_2012Metric_Pad1.05x1.20mm_HandSolder; jlc-part-type B+
J401: RJ45_Shielded; RJ45_FG_RJ-064-1; jlc-part-type E+
R401, R402, R403, R404: 75R; R_0402_1005Metric_Pad0.72x0.64mm_HandSolder; jlc-part-type ER+
R405, R406, R407, R408: 49R9; R_0402_1005Metric_Pad0.72x0.64mm_HandSolder; jlc-part-type B+
R409, R411: 12k4; R_0402_1005Metric_Pad0.72x0.64mm_HandSolder; jlc-part-type E+
R410: 4k7; R_0402_1005Metric_Pad0.72x0.64mm_HandSolder; jlc-part-type B+
R412, R413, R414, R415: 33R; R_0402_1005Metric_Pad0.72x0.64mm_HandSolder; jlc-part-type B+
R416: 1M; R_0402_1005Metric_Pad0.72x0.64mm_HandSolder; jlc-part-type B+
TR401: CND-tek-H1102N; Transformer_Ethernet_SO-16_7.11x12.7mm; jlc-part-type E+
U401: W5500; LQFP-48_7x7mm_P0.5mm; jlc-part-type E+
Y401: 25MHz; Crystal_SMD_2016-4Pin_2.0x1.6mm; jlc-part-type E+

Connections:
3V3: C420.1, C421.1, FB401.2, U401.28 (VDD); also elsewhere on the board
/ETH/1V2: C417.1, U401.22 (1V2O)
/ETH/3V3A: C407.1, C411.1, C412.1, C413.1, C414.1, C416.1, C418.1, C419.1, FB401.1, R405.2, R406.2, TR401.2 (C_TD), TR401.7 (C_RD), U401.4 (AVDD), U401.8 (AVDD), U401.11 (AVDD), U401.15 (AVDD), U401.17 (AVDD), U401.21 (AVDD)
/ETH/A: C406.1, TR401.15 (C_TX); also elsewhere on the board
/ETH/ACT_LED: R411.2, U401.27 (ACTLED)
/ETH/B: C403.1, TR401.10 (C_RX); also elsewhere on the board
/ETH/C: C402.1, J401.4, J401.5; also elsewhere on the board
/ETH/CLK: U401.33 (SCLK); also elsewhere on the board
/ETH/CS: U401.32 (~SCS); also elsewhere on the board
/ETH/D: C401.1, J401.7, J401.8; also elsewhere on the board
/ETH/ETH_GND: C404.2, C405.1, J401.SH
/ETH/EXRES1: R409.2, U401.10 (EXRES1)
/ETH/INT: U401.36 (~INT); also elsewhere on the board
/ETH/LNK_LED: R410.1, U401.25 (LINKLED)
/ETH/MISO: U401.34 (MISO); also elsewhere on the board
/ETH/MOSI: U401.35 (MOSI); also elsewhere on the board
/ETH/PHY_RXC_N: C409.2, R408.2, R414.1
/ETH/PHY_RXC_P: C408.2, R407.2, R415.1
/ETH/PHY_RXM_N: C409.1, TR401.8 (RD-)
/ETH/PHY_RXM_P: C408.1, TR401.6 (RD+)
/ETH/PHY_RX_N: R414.2, U401.5 (RXN)
/ETH/PHY_RX_P: R415.2, U401.6 (RXP)
/ETH/PHY_TXM_N: R406.1, R412.1, TR401.3 (TD-)
/ETH/PHY_TXM_P: R405.1, R413.1, TR401.1 (TD+)
/ETH/PHY_TX_N: R412.2, U401.1 (TXN)
/ETH/PHY_TX_P: R413.2, U401.2 (TXP)
/ETH/TERM_COM: C404.1, R401.1, R402.1, R403.1, R404.1
/ETH/TOCAP: C415.1, U401.20 (TOCAP)
/ETH/XI: C423.1, R416.2, U401.30 (XI/CLKIN), Y401.3
/ETH/XO: C422.1, R416.1, U401.31 (XO), Y401.1
EN: U401.37 (~RST); also elsewhere on the board
ETH_LED: R410.2, R411.1; also elsewhere on the board
GND: C405.2, C407.2, C410.2, C411.2, C412.2, C413.2, C414.2, C415.2, C416.2, C417.2, C418.2, C419.2, C420.2, C421.2, C422.2, C423.2, R409.1, U401.3 (AGND), U401.9 (AGND), U401.14 (AGND), U401.16 (AGND), U401.19 (AGND), U401.29 (GND), U401.48 (AGND), Y401.2, Y401.4; also elsewhere on the board
unnamed: C401.2, R401.2
unnamed: C402.2, R402.2
unnamed: C403.2, R403.2
unnamed: C406.2, R404.2
unnamed: C410.1, R407.1, R408.1
unnamed: J401.1, TR401.16 (TX+)
unnamed: J401.2, TR401.14 (TX-)
unnamed: J401.3, TR401.11 (RX+)
unnamed: J401.6, TR401.9 (RX-)

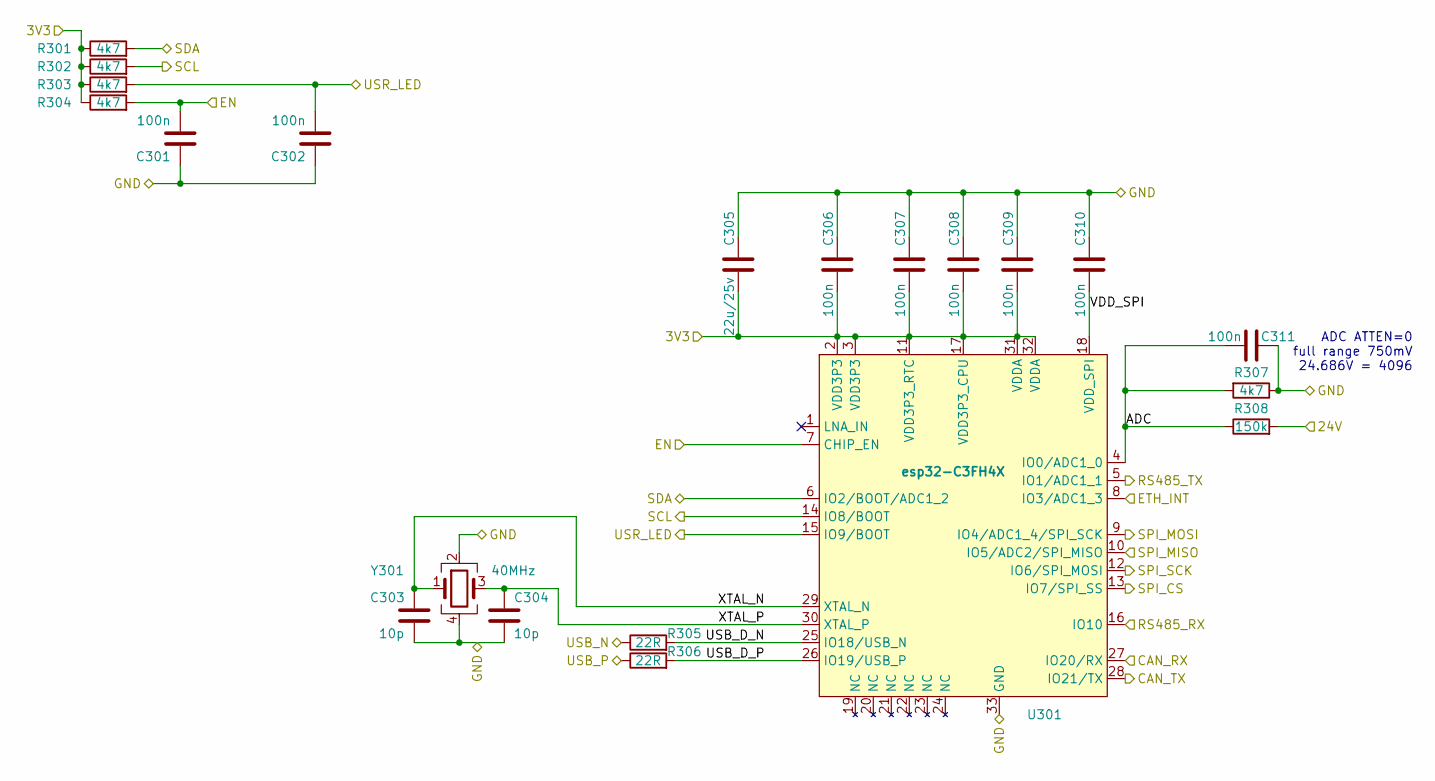
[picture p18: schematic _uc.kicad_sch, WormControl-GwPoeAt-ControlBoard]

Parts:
C301, C302, C306, C307, C308, C309, C310, C311: 100n; C_0402_1005Metric_Pad0.74x0.62mm_HandSolder; jlc-part-type B+
C303, C304: 10p; C_0402_1005Metric_Pad0.74x0.62mm_HandSolder; jlc-part-type B+
C305: 22u/25v; C_0805_2012Metric_Pad1.18x1.45mm_HandSolder; jlc-part-type B+
R301, R302, R303, R304, R307: 4k7; R_0402_1005Metric_Pad0.72x0.64mm_HandSolder; jlc-part-type B+
R305, R306: 22R; R_0402_1005Metric_Pad0.72x0.64mm_HandSolder; jlc-part-type B+
R308: 150k; R_0805_2012Metric_Pad1.20x1.40mm_HandSolder; jlc-part-type B+
U301: esp32-C3FH4X; QFN-32-1EP_5x5mm_P0.5mm_EP3.65x3.65mm; jlc-part-type E+
Y301: 40MHz; Crystal_SMD_2016-4Pin_2.0x1.6mm; jlc-part-type E+

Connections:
3V3: C305.2, C306.1, C307.1, C308.1, C309.1, R301.1, R302.1, R303.1, R304.1, U301.2 (VDD3P3), U301.3 (VDD3P3), U301.11 (VDD3P3_RTC), U301.17 (VDD3P3_CPU), U301.31 (VDDA), U301.32 (VDDA); also elsewhere on the board
24V: R308.2; also elsewhere on the board
/uC/ADC: C311.1, R307.2, R308.1, U301.4 (IO0/ADC1_0); also elsewhere on the board
/uC/USB_D_N: R305.2, U301.25 (IO18/USB_N); also elsewhere on the board
/uC/USB_D_P: R306.2, U301.26 (IO19/USB_P); also elsewhere on the board
/uC/VDD_SPI: C310.1, U301.18 (VDD_SPI); also elsewhere on the board
/uC/XTAL_N: C303.1, U301.29 (XTAL_N), Y301.1; also elsewhere on the board
/uC/XTAL_P: C304.1, U301.30 (XTAL_P), Y301.3; also elsewhere on the board
EN: C301.2, R304.2, U301.7 (CHIP_EN); also elsewhere on the board
GND: C301.1, C302.1, C303.2, C304.2, C305.1, C306.2, C307.2, C308.2, C309.2, C310.2, C311.2, R307.1, U301.33 (GND), Y301.2, Y301.4; also elsewhere on the board
SCL: R302.2, U301.14 (IO8/BOOT); also elsewhere on the board
SDA: R301.2, U301.6 (IO2/BOOT/ADC1_2); also elsewhere on the board
USB_N: R305.1; also elsewhere on the board
USB_P: R306.1; also elsewhere on the board
USR_LED: C302.2, R303.2, U301.15 (IO9/BOOT); also elsewhere on the board

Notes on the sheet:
ADC ATTEN=0 full range 750mV 24.686V = 4096

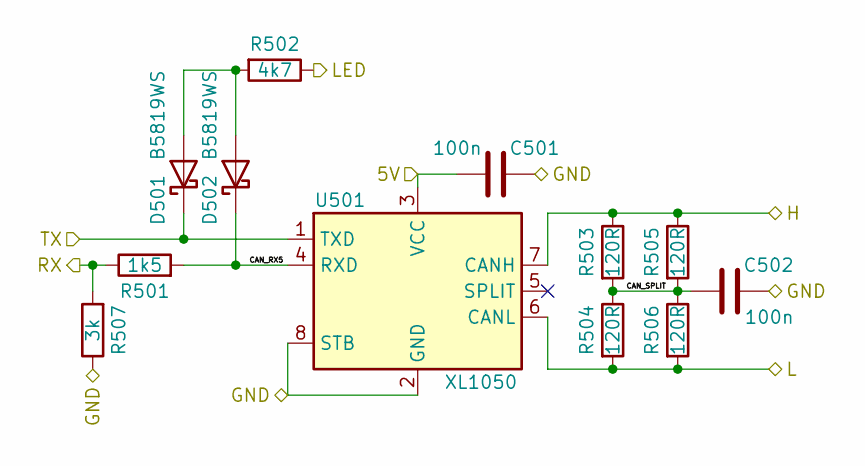
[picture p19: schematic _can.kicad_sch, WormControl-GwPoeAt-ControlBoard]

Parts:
C501, C502: 100n; C_0402_1005Metric_Pad0.74x0.62mm_HandSolder; jlc-part-type B+
D501, D502: B5819WS; D_SOD-323_HandSoldering; jlc-part-type B+
R501: 1k5; R_0402_1005Metric_Pad0.72x0.64mm_HandSolder; jlc-part-type B+
R502: 4k7; R_0402_1005Metric_Pad0.72x0.64mm_HandSolder; jlc-part-type B+
R503, R504, R505, R506: 120R; R_0805_2012Metric_Pad1.20x1.40mm_HandSolder; jlc-part-type B+
R507: 3k; R_0402_1005Metric_Pad0.72x0.64mm_HandSolder; jlc-part-type B+
U501: XL1050; SOIC-8_3.9x4.9mm_P1.27mm; jlc-part-type E+

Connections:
5V: C501.1, U501.3 (VCC); also elsewhere on the board
/CAN/CAN_RX5: D502.1 (K), R501.2, U501.4 (RXD)
/CAN/CAN_SPLIT: C502.1, R503.2, R504.1, R505.2, R506.1
/CAN_RX: R501.1, R507.2; also elsewhere on the board
/CAN_TX: D501.1 (K), U501.1 (TXD); also elsewhere on the board
CANH: R503.1, R505.1, U501.7 (CANH); also elsewhere on the board
CANL: R504.2, R506.2, U501.6 (CANL); also elsewhere on the board
CAN_LED: R502.1; also elsewhere on the board
GND: C501.2, C502.2, R507.1, U501.2 (GND), U501.8 (STB); also elsewhere on the board
unnamed: D501.2 (A), D502.2 (A), R502.2

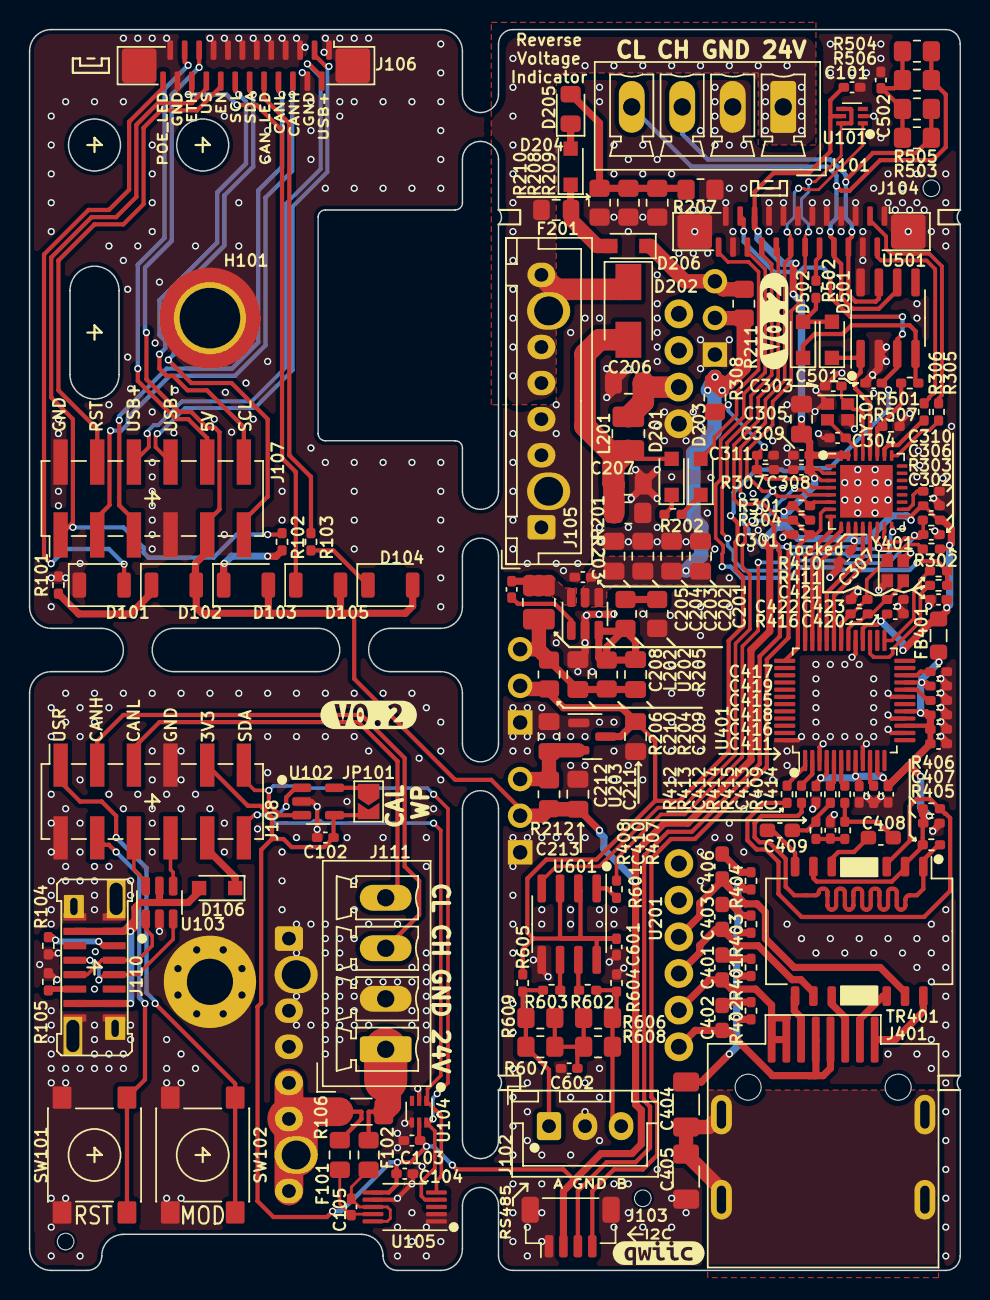
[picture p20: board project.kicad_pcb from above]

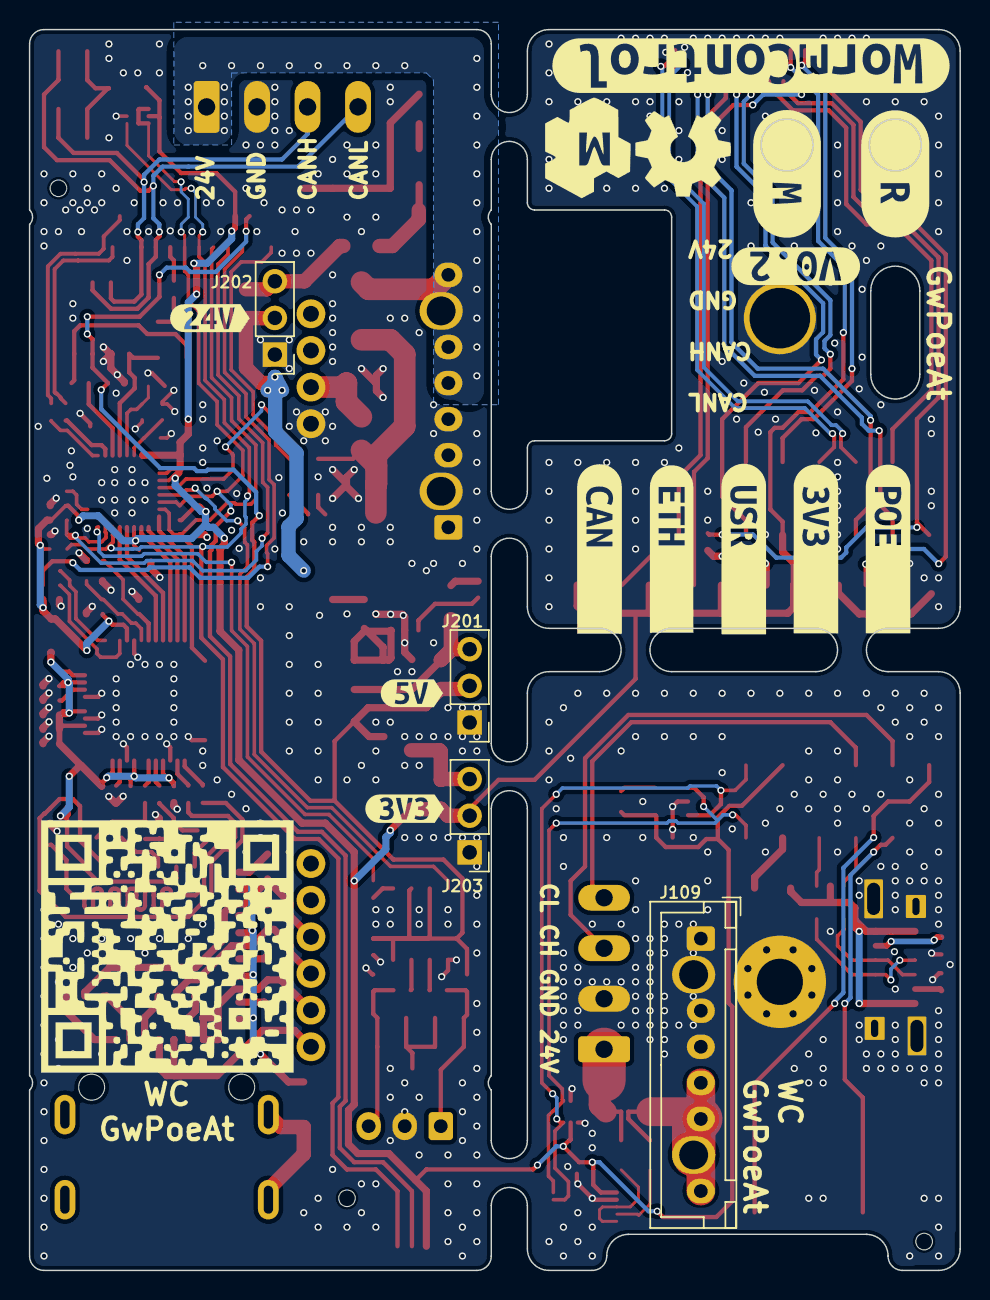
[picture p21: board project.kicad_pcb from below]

Board: 4 copper layers, 64.5 x 86.0 mm, 186 parts (18 on the bottom side), 121 nets.

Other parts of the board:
kibuzzard-6A7A3E96: G***; kibuzzard-6A7A3E96
kibuzzard-6A7A3EB1: G***; kibuzzard-6A7A3EB1
kibuzzard-6A7A3F37: G***; kibuzzard-6A7A3F37
kibuzzard-68F6C7D9: G***; kibuzzard-68F6C7D9
kibuzzard-68F6C776: G***; kibuzzard-68F6C776
kibuzzard-68F6C793: G***; kibuzzard-68F6C793
kibuzzard-69A9CC91: G***; kibuzzard-69A9CC91
kibuzzard-69AA2F96: G***; kibuzzard-69AA2F96
kibuzzard-69AEA4F2: G***; kibuzzard-69AEA4F2
kibuzzard-69AFA227: G***; kibuzzard-69AFA227
kibuzzard-69AFDF3E: G***; kibuzzard-69AFDF3E
kibuzzard-69AFDF44: G***; kibuzzard-69AFDF44
kibuzzard-69938F5C: G***; kibuzzard-69938F5C
kibuzzard-69938F55: G***; kibuzzard-69938F55
kibuzzard-69938F62: G***; kibuzzard-69938F62
locked: esp32-C3FH4X; QFN-32-1EP_5x5mm_P0.5mm_EP3.65x3.65mm

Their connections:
3V3: locked.2 (VDD3P3), locked.3 (VDD3P3), locked.11 (VDD3P3_RTC), locked.17 (VDD3P3_CPU), locked.31 (VDDA), locked.32 (VDDA); also elsewhere on the board
/CAN_RX: locked.27 (IO20/RX); also elsewhere on the board
/CAN_TX: locked.28 (IO21/TX); also elsewhere on the board
/ETH/CLK: locked.12 (IO6/SPI_MOSI); also elsewhere on the board
/ETH/CS: locked.13 (IO7/SPI_SS); also elsewhere on the board
/ETH/INT: locked.8 (IO3/ADC1_3); also elsewhere on the board
/ETH/MISO: locked.10 (IO5/ADC2/SPI_MISO); also elsewhere on the board
/ETH/MOSI: locked.9 (IO4/ADC1_4/SPI_SCK); also elsewhere on the board
/RS485_RX: locked.16 (IO10); also elsewhere on the board
/RS485_TX: locked.5 (IO1/ADC1_1); also elsewhere on the board
/uC/ADC: locked.4 (IO0/ADC1_0); also elsewhere on the board
/uC/USB_D_N: locked.25 (IO18/USB_N); also elsewhere on the board
/uC/USB_D_P: locked.26 (IO19/USB_P); also elsewhere on the board
/uC/VDD_SPI: locked.18 (VDD_SPI); also elsewhere on the board
/uC/XTAL_N: locked.29 (XTAL_N); also elsewhere on the board
/uC/XTAL_P: locked.30 (XTAL_P); also elsewhere on the board
EN: locked.7 (CHIP_EN); also elsewhere on the board
GND: locked.33 (GND); also elsewhere on the board
SCL: locked.14 (IO8/BOOT); also elsewhere on the board
SDA: locked.6 (IO2/BOOT/ADC1_2); also elsewhere on the board
USR_LED: locked.15 (IO9/BOOT); also elsewhere on the board

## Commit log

2026-03-13 initial design
    [_bom.csv, _can.kicad_sch, _eth.kicad_sch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]
2026-03-15 updating poe psu model
    [project.kicad_pcb]
2026-04-20 fix PSU FB and tmp102 pinout
    [_psu.kicad_sch, bom.csv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]
2026-08-10 CAN resistors, power wires and version bump
    * fixing CAN level shifting resistors
    * exposing more copper for power wires between boards
    * bumping up version
    [_bom.csv, _can.kicad_sch, bom.csv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]
2026-08-19 enlarging front pcb to better fit the box
    [project--NPTH_map.gbr, project--PTH_map.gbr, project-B_Cu.gbl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]
2026-08-20 adding fuse to power monitor to prevent reverse polarity damage
    [_bom.csv, bom.csv, bom_lcsc.csv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]
